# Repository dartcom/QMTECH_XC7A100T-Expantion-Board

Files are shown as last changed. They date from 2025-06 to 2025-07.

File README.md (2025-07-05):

# QMTECH_XC7A100T-Expantion-Board
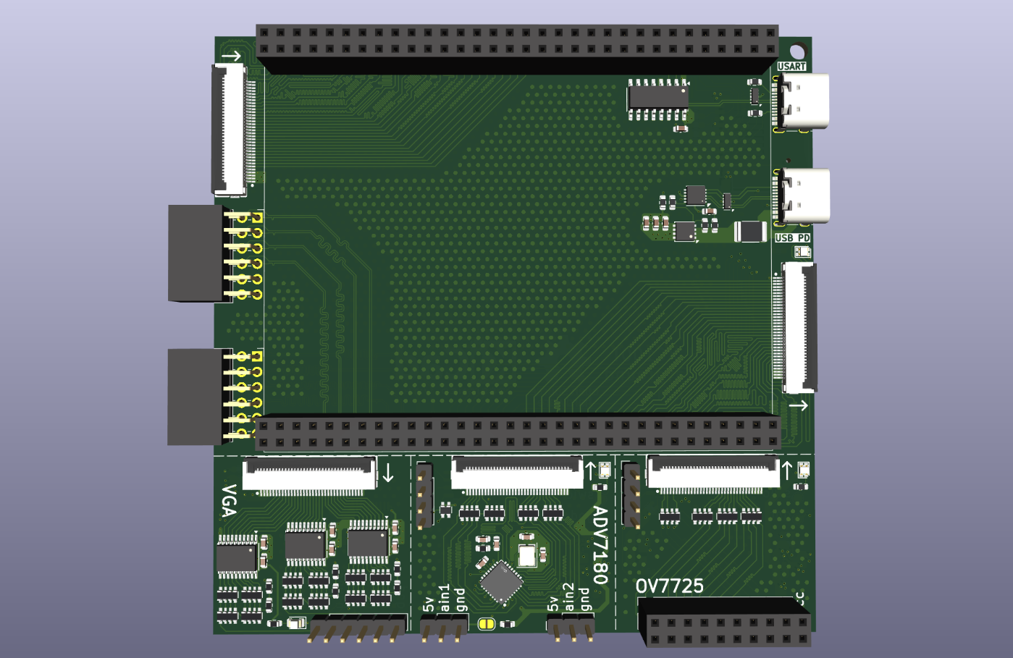
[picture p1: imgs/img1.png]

Expantion board for the QMTECH_XC7A***T series for video processing learning.

This board contains 4 separate designs to save on cost. The boards can be ordered as a single board and then be scored with a fresh exacto knife along the dotted lines ( ! BEWARE to not breathe the FR4 dust as it is VERY harmful ! ).

The main board contains:
- 2 PMOD connectors.
- 2 24bit parallel video connectors. The left is meant to be an input and the right one an output.
- 1 micro sd card slot.
- 1 uart to usb converter.
- 1 usb PD 5v-2A input with overvoltage & overcurrent protection.
- 8 leds.

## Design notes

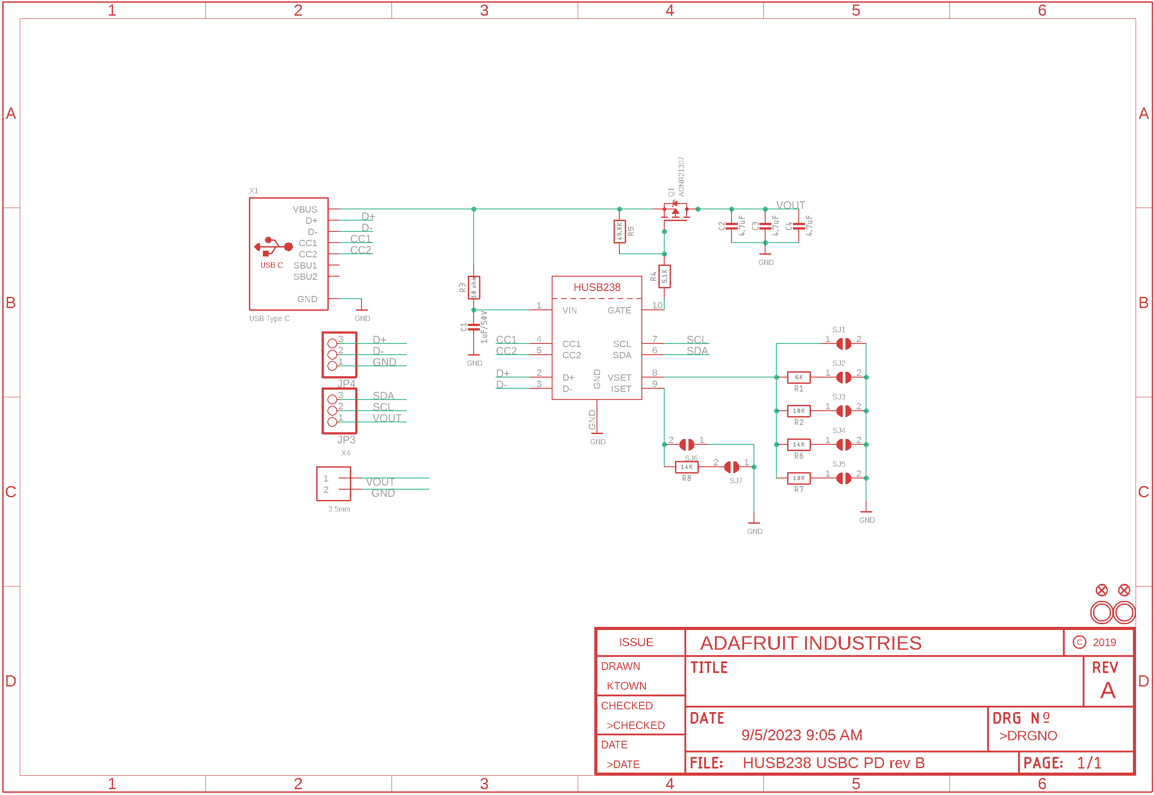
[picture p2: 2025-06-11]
datasheets/power/adafruit_products_schem.png

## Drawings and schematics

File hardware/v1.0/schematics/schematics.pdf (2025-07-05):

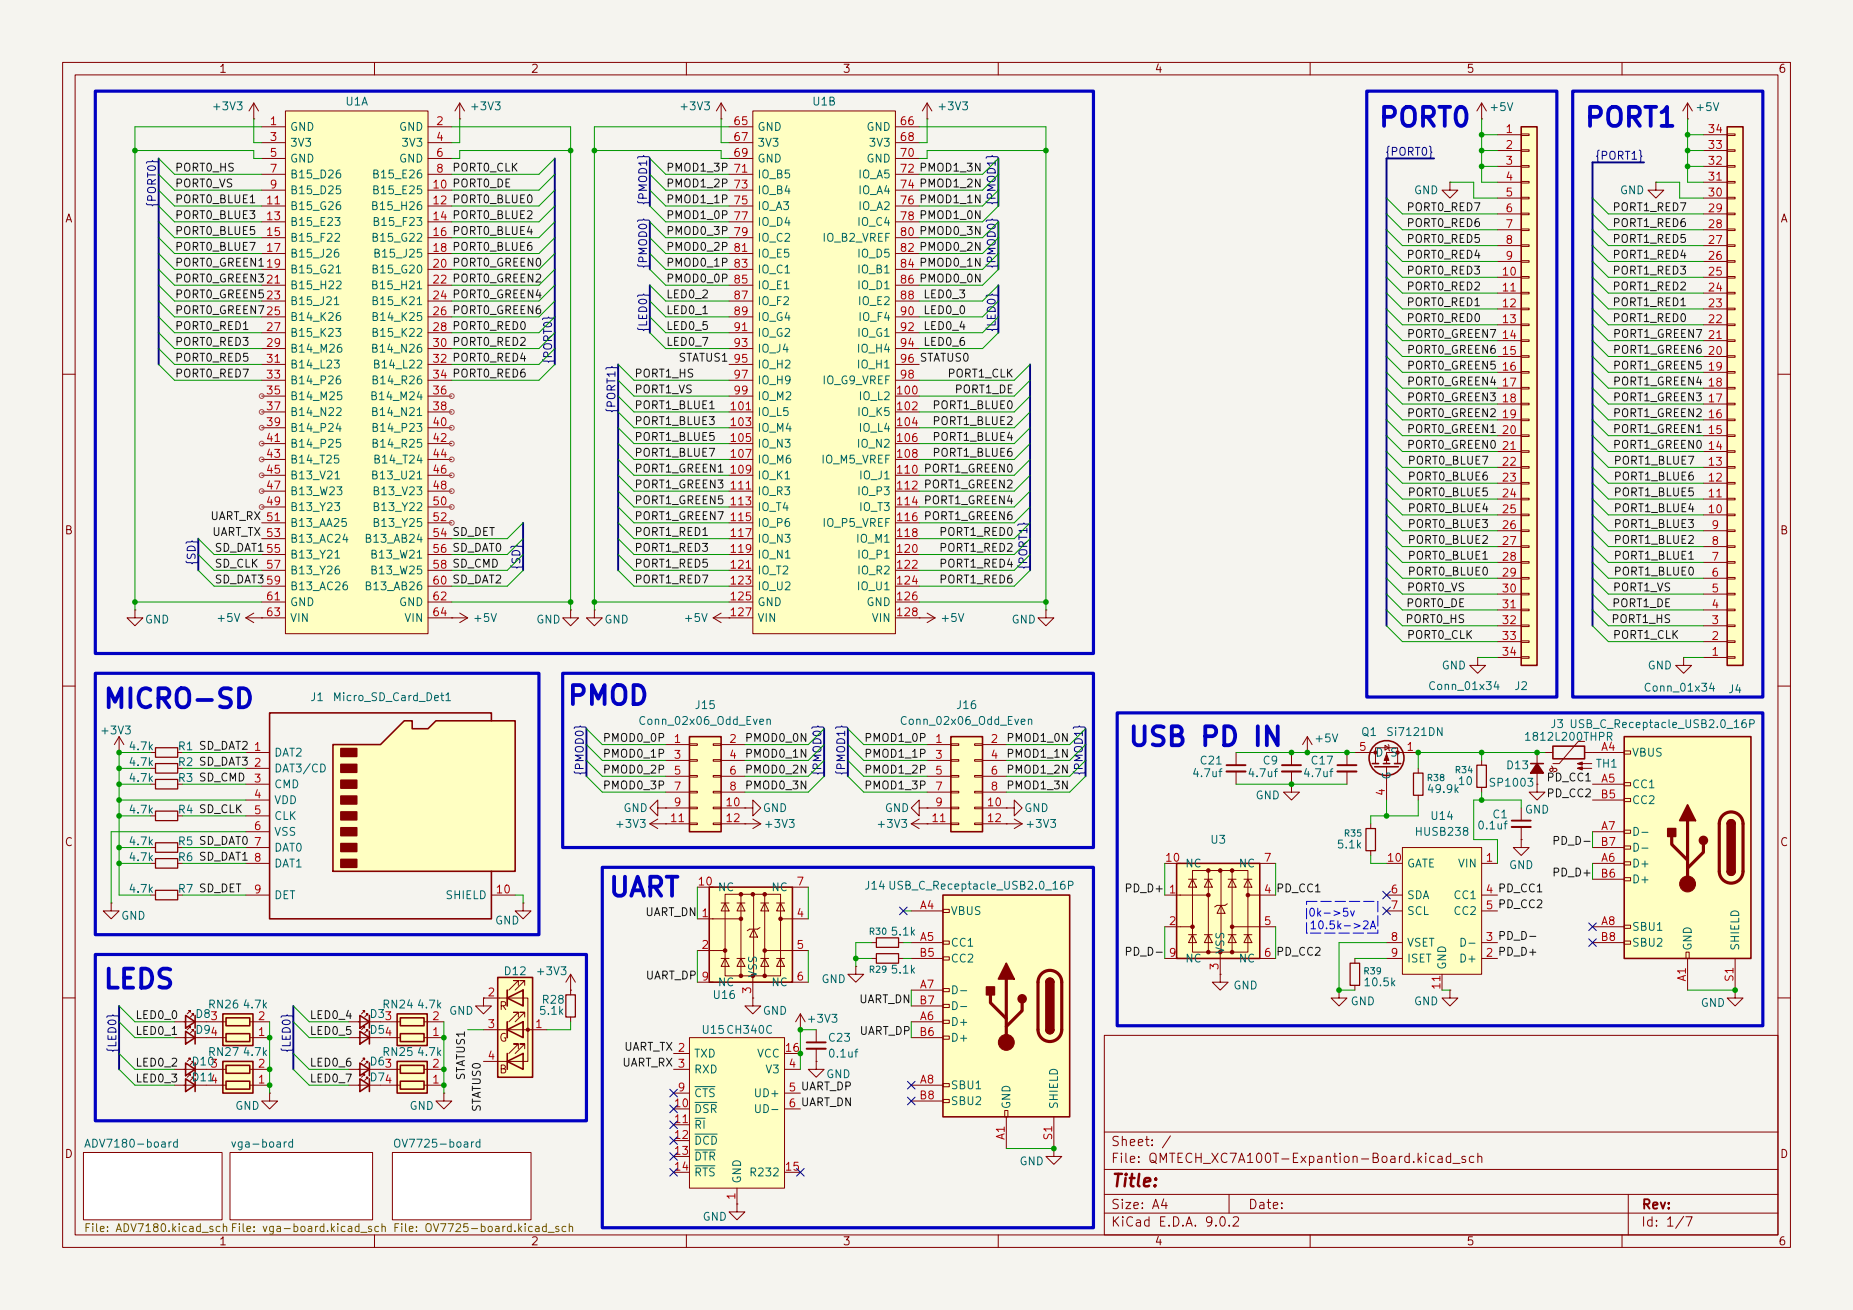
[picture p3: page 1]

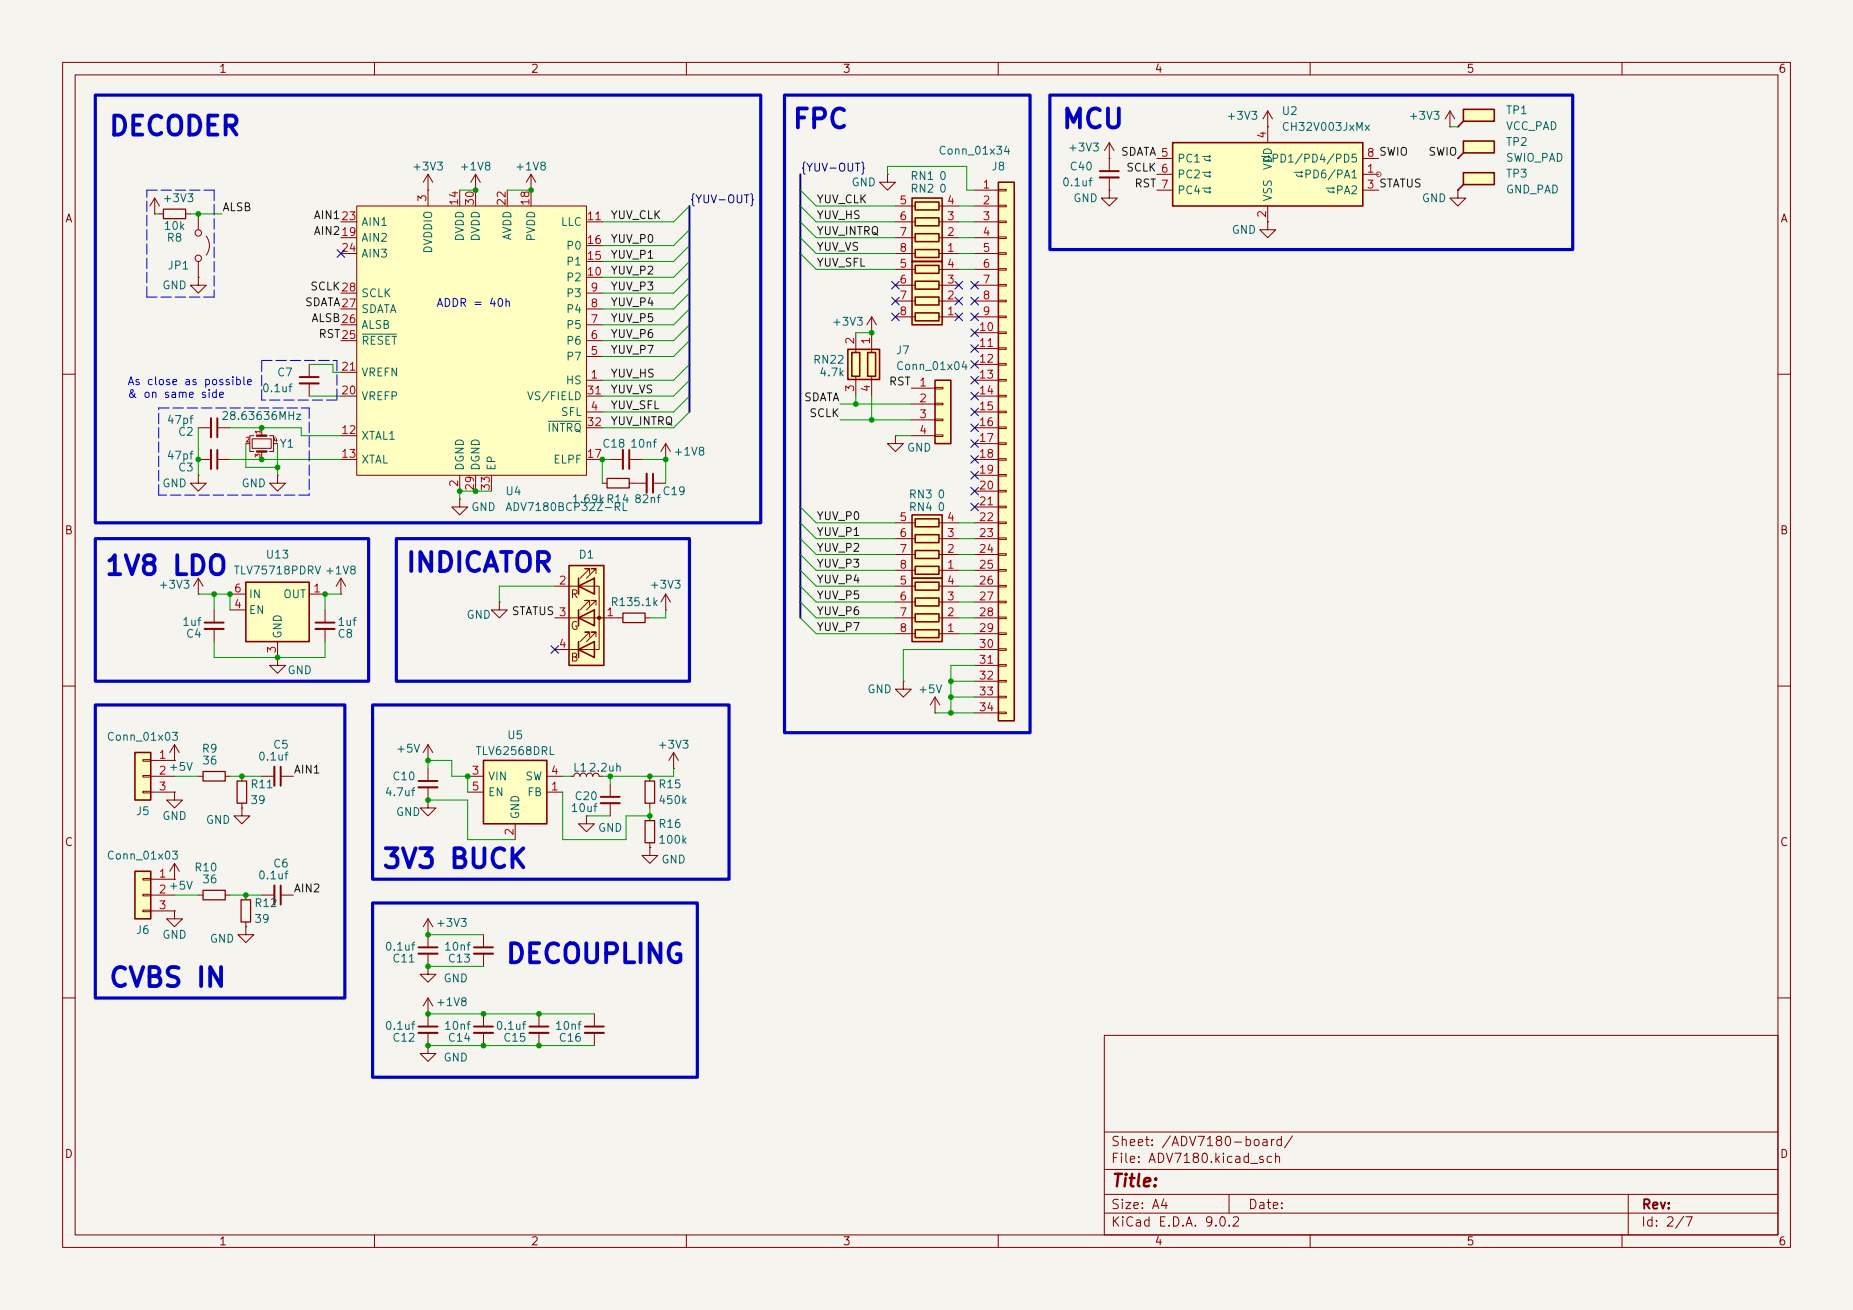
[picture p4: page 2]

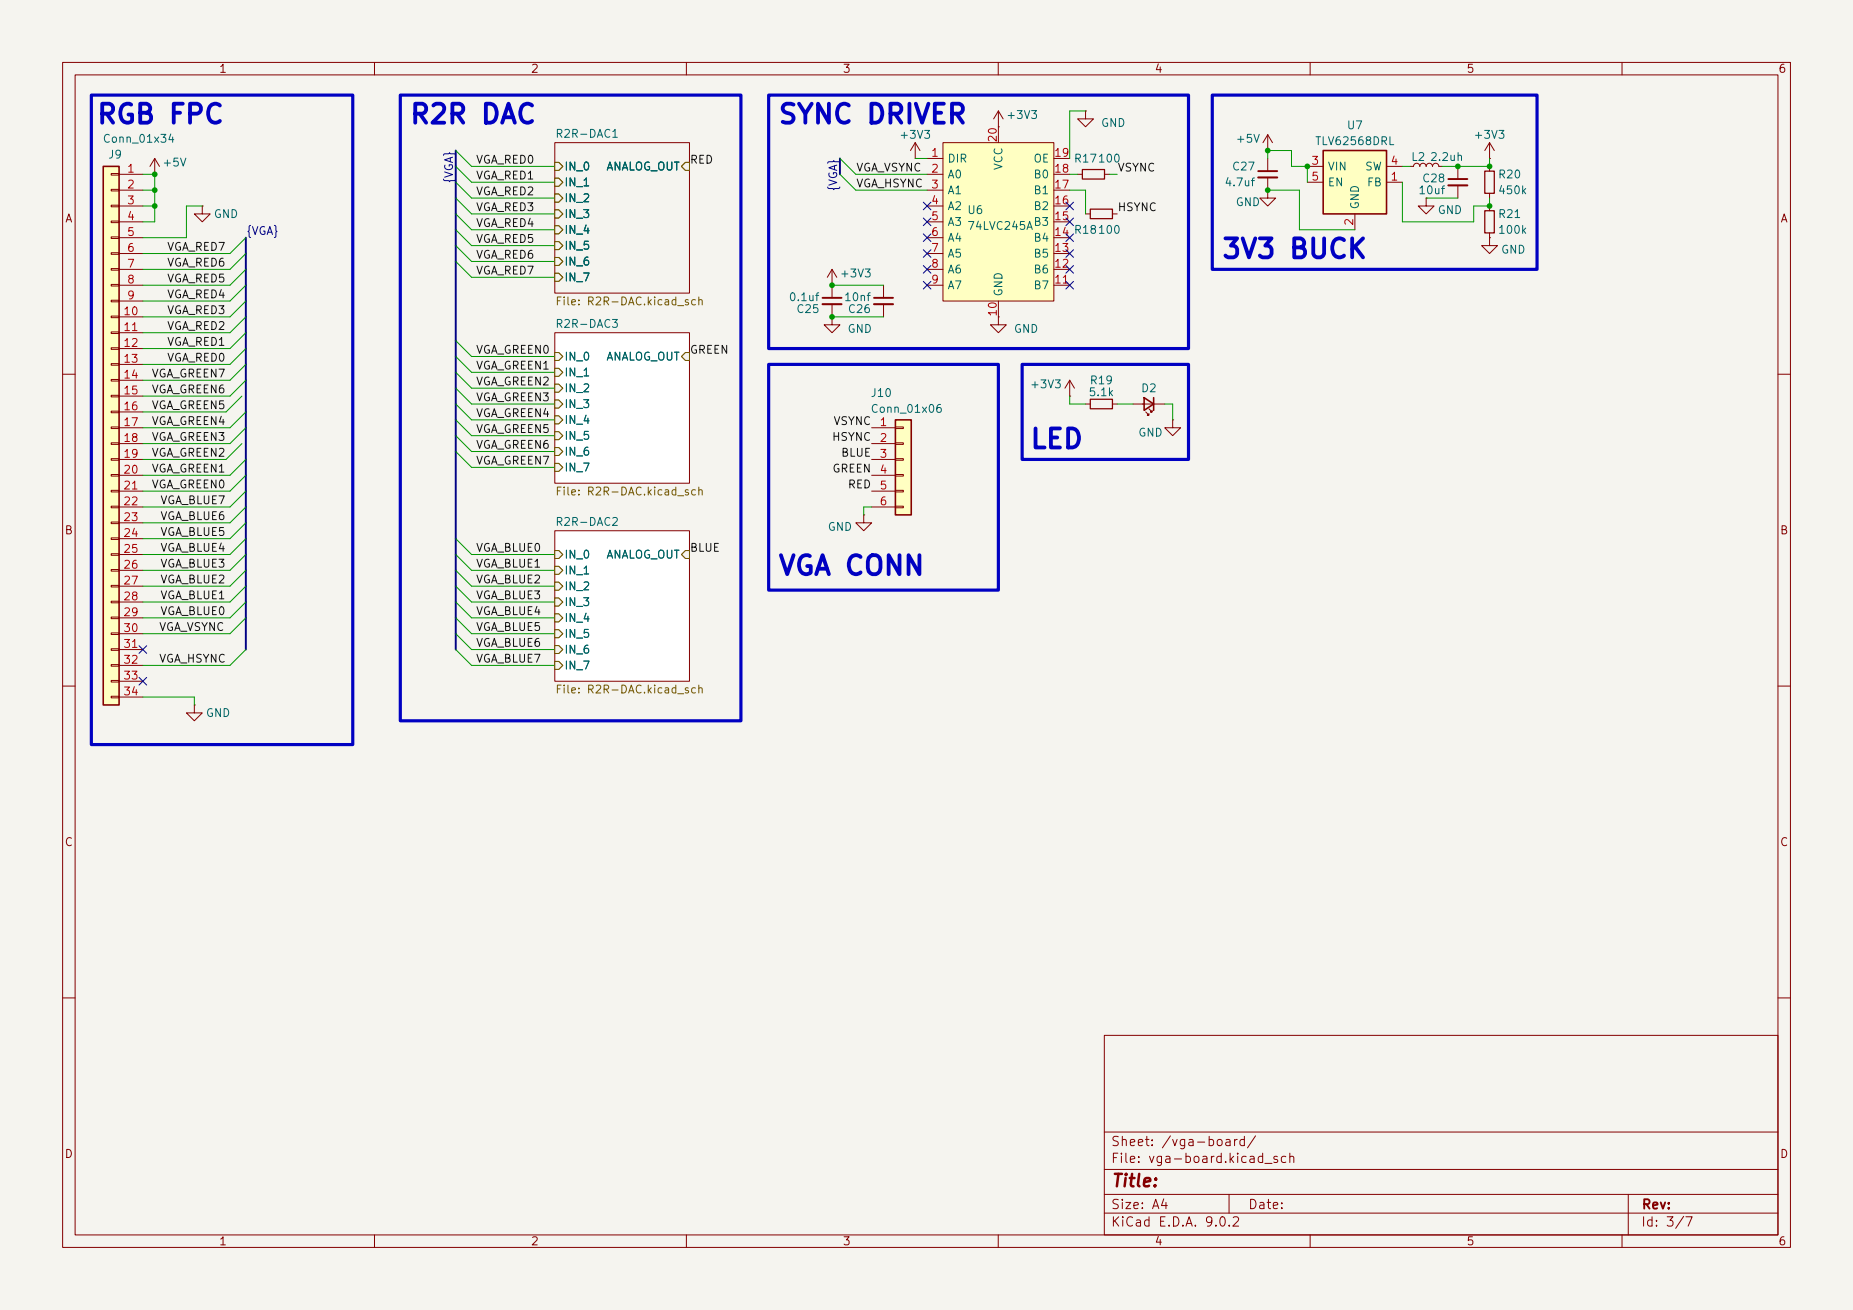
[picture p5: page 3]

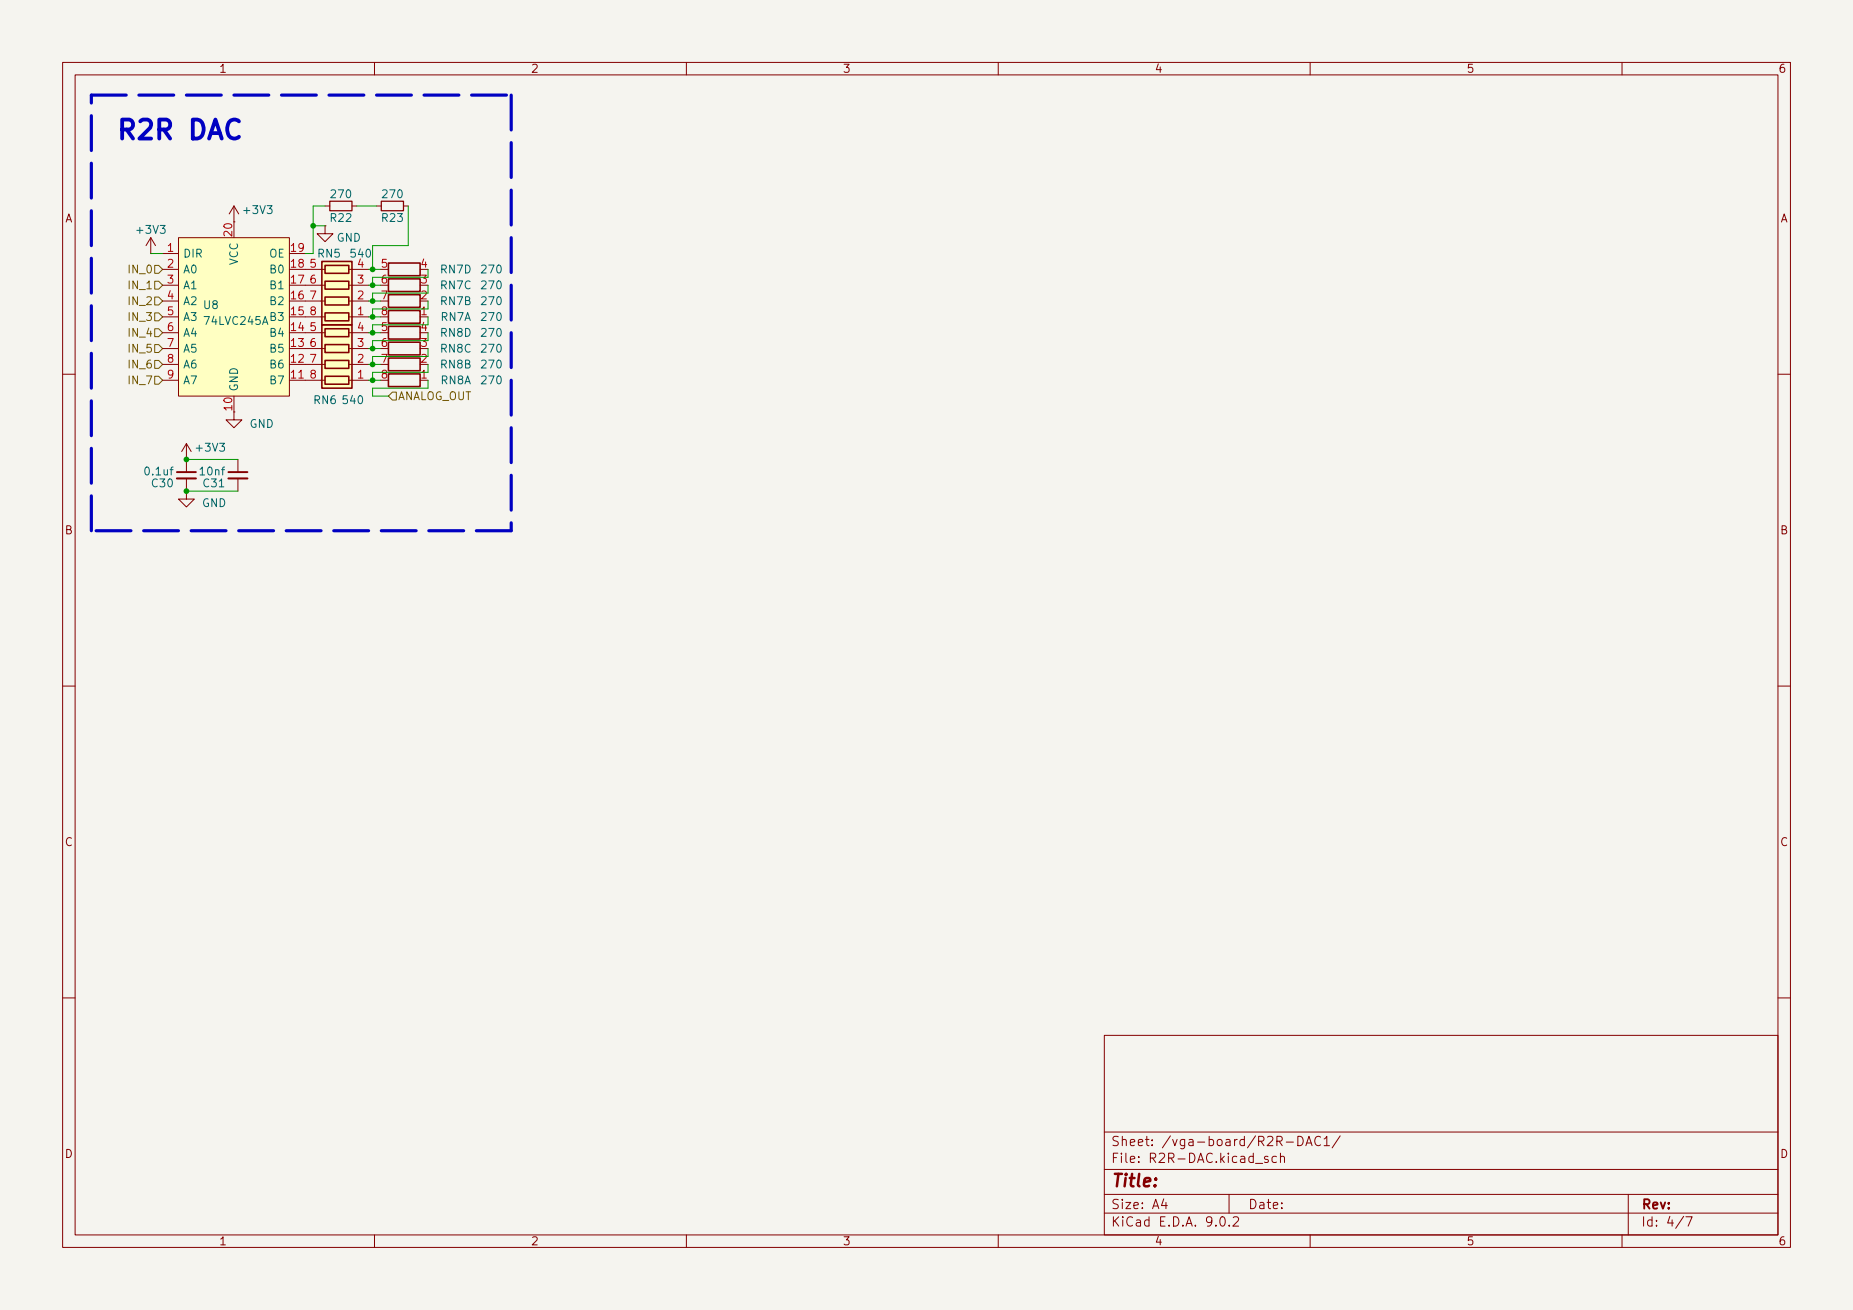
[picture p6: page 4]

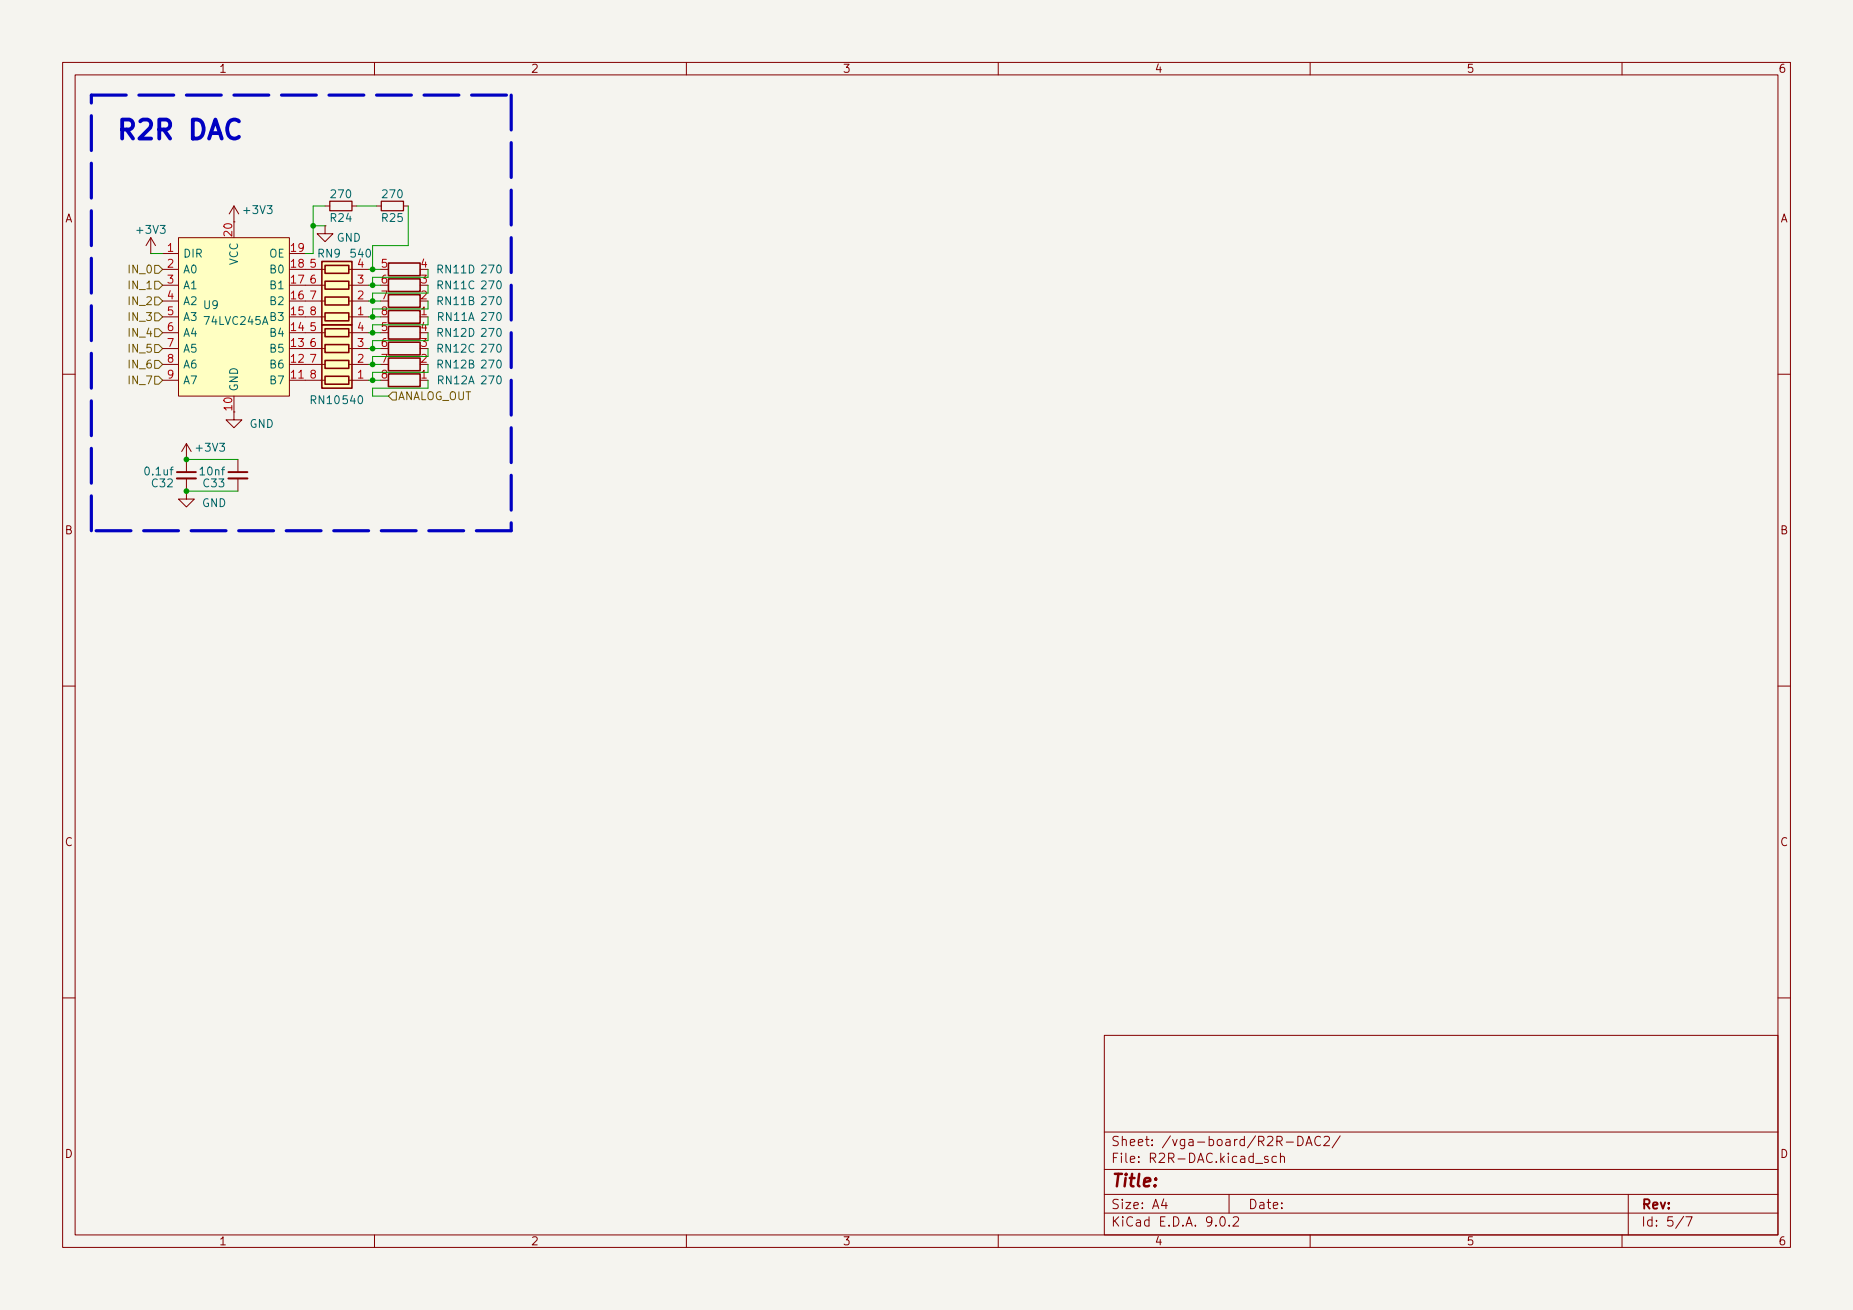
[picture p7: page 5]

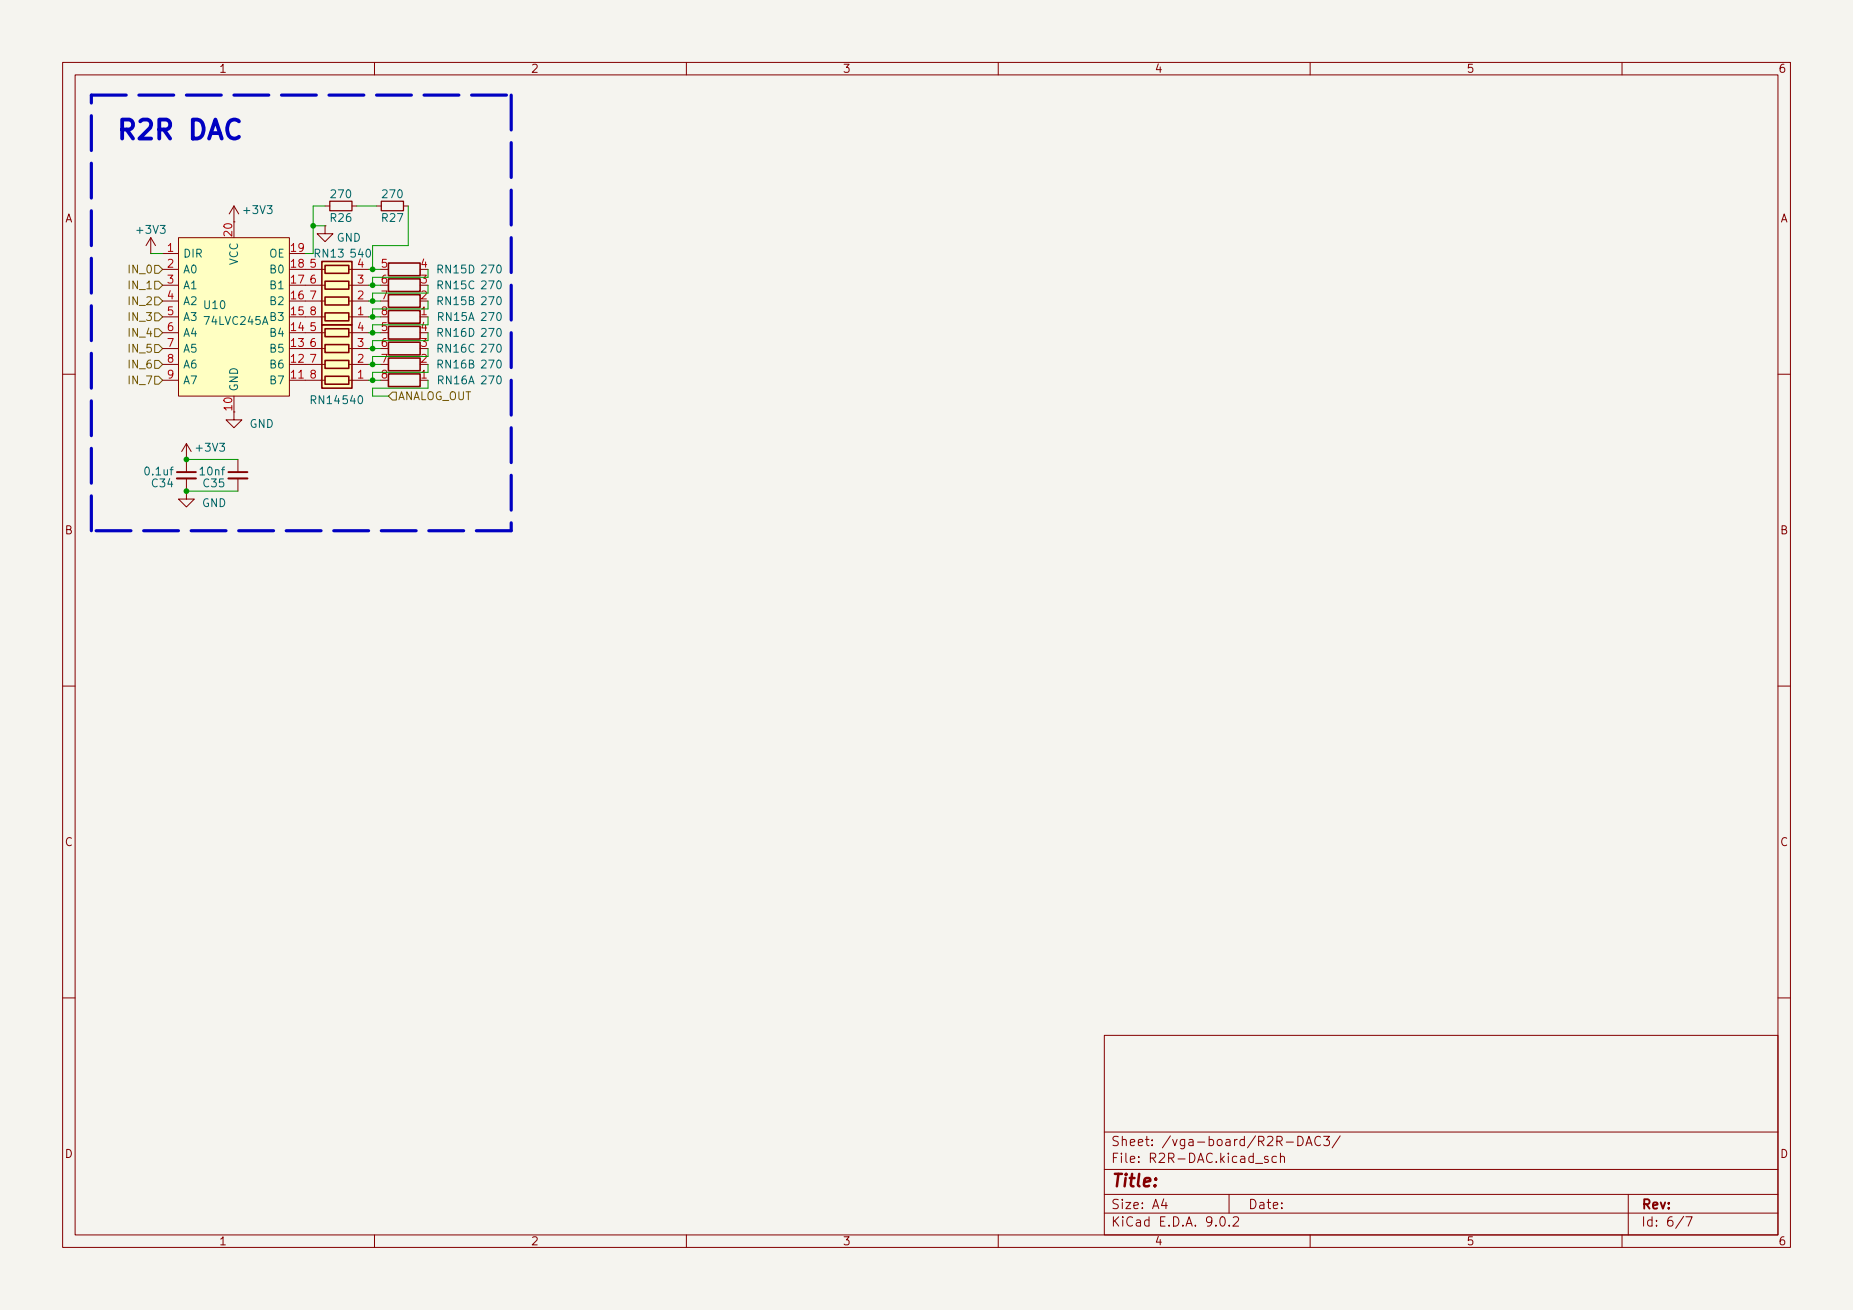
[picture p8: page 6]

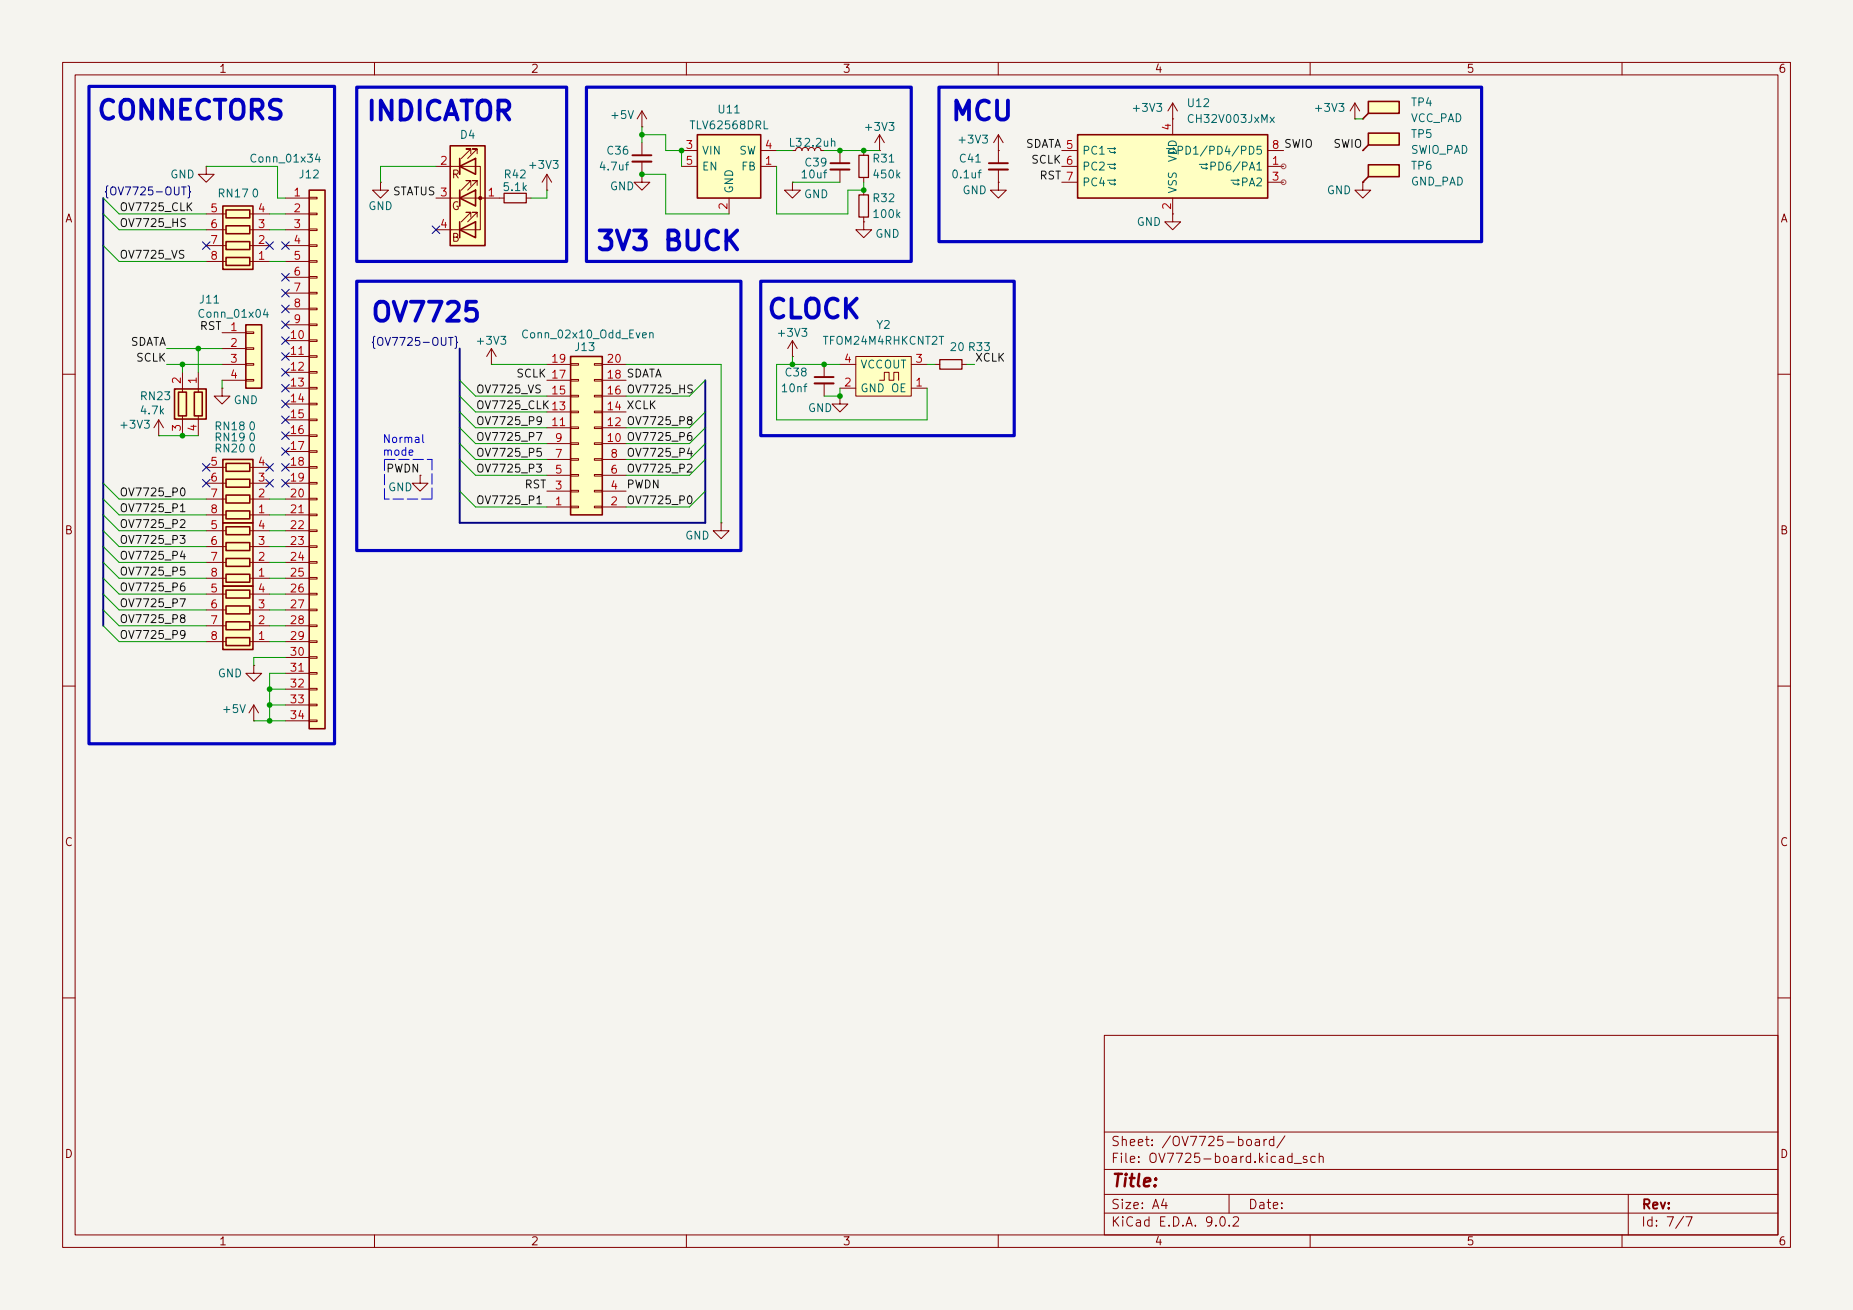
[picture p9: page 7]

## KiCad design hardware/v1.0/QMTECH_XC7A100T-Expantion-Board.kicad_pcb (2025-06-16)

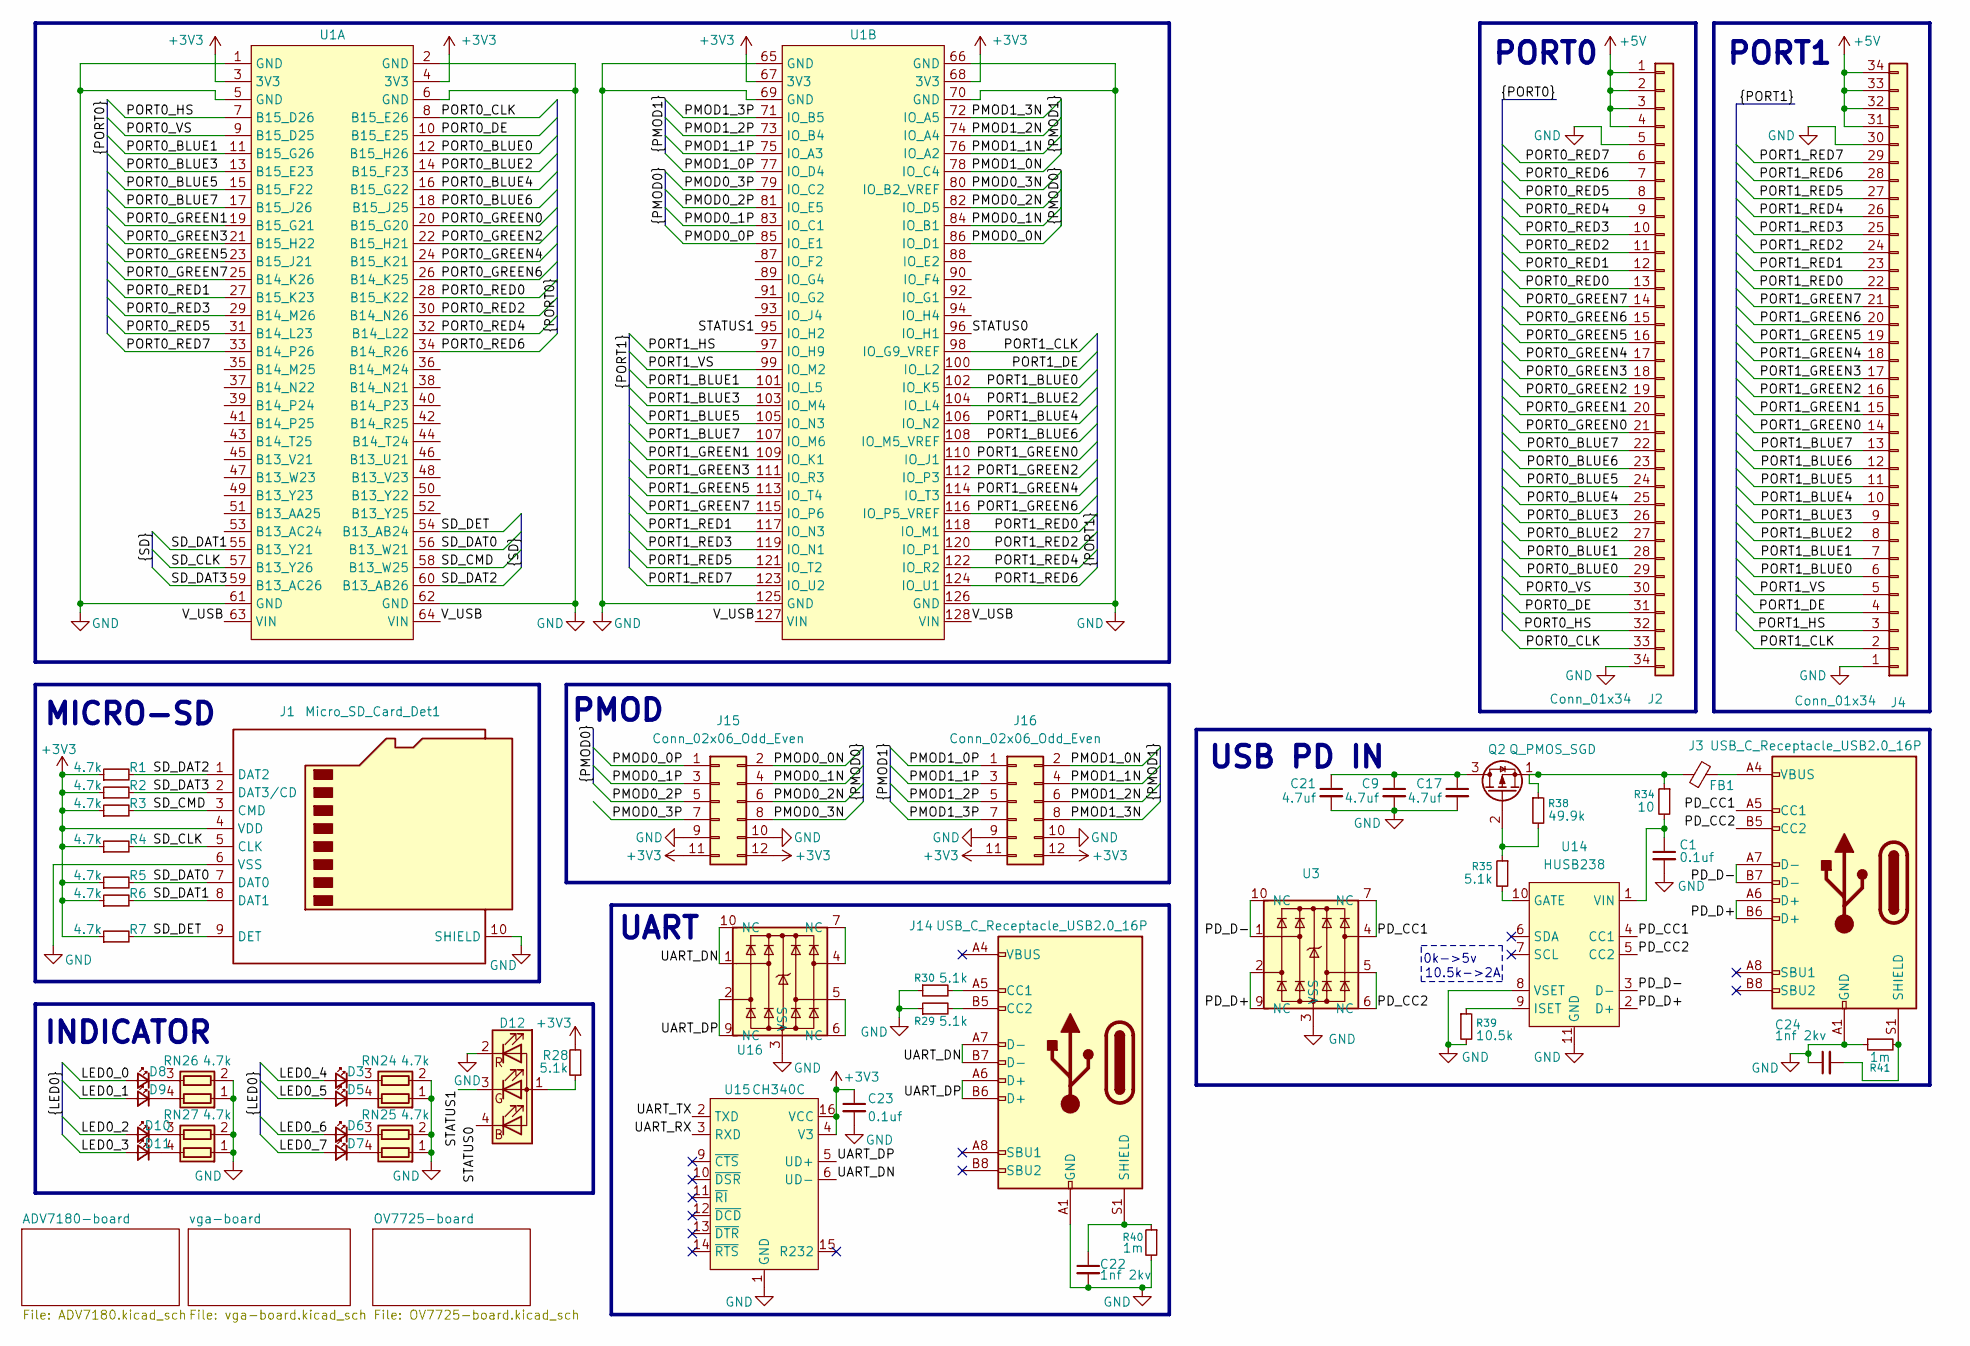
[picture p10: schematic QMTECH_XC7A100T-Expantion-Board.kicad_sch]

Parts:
C1, C23: 0.1uf
C9, C17, C21: 4.7uf
C22, C24: 1nf 2kv
D3, D5, D6, D7, D8, D9, D10, D11: LED_0805_2012Metric
D12: LED-SMD_4P-L1.6-W1.5-BR_TZ-P4-1615
FB1: (no value)
J1: Micro_SD_Card_Det1; TF-SMD_TF-PUSH
J2, J4: Conn_01x34; FPC-SMD_KH-FG0.5-H2.0-34PIN
J3, J14: USB_C_Receptacle_USB2.0_16P; USB_C_Receptacle_Palconn_UTC16-G
J15, J16: Conn_02x06_Odd_Even; PinSocket_2x06_P2.54mm_Horizontal
Q2: Q_PMOS_SGD; DFN-8-1EP_3x3mm_P0.5mm_EP1.7x2.4mm
R1, R2, R3, R4, R5, R6, R7: 4.7k; R_0603_1608Metric_Pad0.98x0.95mm_HandSolder
R28: 5.1k; R_0603_1608Metric_Pad0.98x0.95mm_HandSolder
R29, R30: 5.1k; R_0603_1608Metric
R34: 10
R35: 5.1k
R38: 49.9k
R39: 10.5k
R40, R41: 1m
RN24, RN25, RN26, RN27: 4.7k; R_Array_Convex_2x0603
U1: QMTECH_XC7A___T
U3, U16: Diodes_UDFN-10_1.0x2.5mm_P0.5mm
U14: HUSB238; DFN-10-1EP_3x3mm_P0.5mm_EP1.65x2.38mm_ThermalVias
U15: CH340C; SOIC-16_3.9x9.9mm_P1.27mm

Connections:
+3V3: C23.1, J1.4 (VDD), J15.11, J15.12, J16.11, J16.12, R1.1, R2.1, R3.1, R4.1, R5.1, R6.1, R7.1, R28.2, U1.3 (3V3), U1.4 (3V3), U1.67 (3V3), U1.68 (3V3), U15.4 (V3), U15.16 (VCC); also elsewhere on the board
+5V: J2.1, J2.2, J2.3, J2.4, J4.31, J4.32, J4.33, J4.34; also elsewhere on the board
/LED0_0: D8.2 (A)
/LED0_1: D9.2 (A)
/LED0_2: D10.2 (A)
/LED0_3: D11.2 (A)
/LED0_4: D3.2 (A)
/LED0_5: D5.2 (A)
/LED0_6: D6.2 (A)
/LED0_7: D7.2 (A)
/PD_CC1: J3.A5 (CC1), U3.4, U3.7 (NC), U14.4 (CC1)
/PD_CC2: J3.B5 (CC2), U3.5, U3.6 (NC), U14.5 (CC2)
/PD_D+: J3.A6 (D+), J3.B6 (D+), U3.2, U3.9 (NC), U14.2 (D+)
/PD_D-: J3.A7 (D-), J3.B7 (D-), U3.1, U3.10 (NC), U14.3 (D-)
/PMOD0_0N: J15.2, U1.86 (IO_D1)
/PMOD0_0P: J15.1, U1.85 (IO_E1)
/PMOD0_1N: J15.4, U1.84 (IO_B1)
/PMOD0_1P: J15.3, U1.83 (IO_C1)
/PMOD0_2N: J15.6, U1.82 (IO_D5)
/PMOD0_2P: J15.5, U1.81 (IO_E5)
/PMOD0_3N: J15.8, U1.80 (IO_B2_VREF)
/PMOD0_3P: J15.7, U1.79 (IO_C2)
/PMOD1_0N: J16.2, U1.78 (IO_C4)
/PMOD1_0P: J16.1, U1.77 (IO_D4)
/PMOD1_1N: J16.4, U1.76 (IO_A2)
/PMOD1_1P: J16.3, U1.75 (IO_A3)
/PMOD1_2N: J16.6, U1.74 (IO_A4)
/PMOD1_2P: J16.5, U1.73 (IO_B4)
/PMOD1_3N: J16.8, U1.72 (IO_A5)
/PMOD1_3P: J16.7, U1.71 (IO_B5)
/PORT0_BLUE0: J2.29, U1.12 (B15_H26)
/PORT0_BLUE1: J2.28, U1.11 (B15_G26)
/PORT0_BLUE2: J2.27, U1.14 (B15_F23)
/PORT0_BLUE3: J2.26, U1.13 (B15_E23)
/PORT0_BLUE4: J2.25, U1.16 (B15_G22)
/PORT0_BLUE5: J2.24, U1.15 (B15_F22)
/PORT0_BLUE6: J2.23, U1.18 (B15_J25)
/PORT0_BLUE7: J2.22, U1.17 (B15_J26)
/PORT0_CLK: J2.33, U1.8 (B15_E26)
/PORT0_DE: J2.31, U1.10 (B15_E25)
/PORT0_GREEN0: J2.21, U1.20 (B15_G20)
/PORT0_GREEN1: J2.20, U1.19 (B15_G21)
/PORT0_GREEN2: J2.19, U1.22 (B15_H21)
/PORT0_GREEN3: J2.18, U1.21 (B15_H22)
/PORT0_GREEN4: J2.17, U1.24 (B15_K21)
/PORT0_GREEN5: J2.16, U1.23 (B15_J21)
/PORT0_GREEN6: J2.15, U1.26 (B14_K25)
/PORT0_GREEN7: J2.14, U1.25 (B14_K26)
/PORT0_HS: J2.32, U1.7 (B15_D26)
/PORT0_RED0: J2.13, U1.28 (B15_K22)
/PORT0_RED1: J2.12, U1.27 (B15_K23)
/PORT0_RED2: J2.11, U1.30 (B14_N26)
/PORT0_RED3: J2.10, U1.29 (B14_M26)
/PORT0_RED4: J2.9, U1.32 (B14_L22)
/PORT0_RED5: J2.8, U1.31 (B14_L23)
/PORT0_RED6: J2.7, U1.34 (B14_R26)
/PORT0_RED7: J2.6, U1.33 (B14_P26)
/PORT0_VS: J2.30, U1.9 (B15_D25)
/PORT1_BLUE0: J4.6, U1.102 (IO_K5)
/PORT1_BLUE1: J4.7, U1.101 (IO_L5)
/PORT1_BLUE2: J4.8, U1.104 (IO_L4)
/PORT1_BLUE3: J4.9, U1.103 (IO_M4)
/PORT1_BLUE4: J4.10, U1.106 (IO_N2)
/PORT1_BLUE5: J4.11, U1.105 (IO_N3)
/PORT1_BLUE6: J4.12, U1.108 (IO_M5_VREF)
/PORT1_BLUE7: J4.13, U1.107 (IO_M6)
/PORT1_CLK: J4.2, U1.98 (IO_G9_VREF)
/PORT1_DE: J4.4, U1.100 (IO_L2)
/PORT1_GREEN0: J4.14, U1.110 (IO_J1)
/PORT1_GREEN1: J4.15, U1.109 (IO_K1)
/PORT1_GREEN2: J4.16, U1.112 (IO_P3)
/PORT1_GREEN3: J4.17, U1.111 (IO_R3)
/PORT1_GREEN4: J4.18, U1.114 (IO_T3)
/PORT1_GREEN5: J4.19, U1.113 (IO_T4)
/PORT1_GREEN6: J4.20, U1.116 (IO_P5_VREF)
/PORT1_GREEN7: J4.21, U1.115 (IO_P6)
/PORT1_HS: J4.3, U1.97 (IO_H9)
/PORT1_RED0: J4.22, U1.118 (IO_M1)
/PORT1_RED1: J4.23, U1.117 (IO_N3)
/PORT1_RED2: J4.24, U1.120 (IO_P1)
/PORT1_RED3: J4.25, U1.119 (IO_N1)
/PORT1_RED4: J4.26, U1.122 (IO_R2)
/PORT1_RED5: J4.27, U1.121 (IO_T2)
/PORT1_RED6: J4.28, U1.124 (IO_U1)
/PORT1_RED7: J4.29, U1.123 (IO_U2)
/PORT1_VS: J4.5, U1.99 (IO_M2)
/SD_CLK: J1.5 (CLK), R4.2, U1.57 (B13_Y26)
/SD_CMD: J1.3 (CMD), R3.2, U1.58 (B13_W25)
/SD_DAT0: J1.7 (DAT0), R5.2, U1.56 (B13_W21)
/SD_DAT1: J1.8 (DAT1), R6.2, U1.55 (B13_Y21)
/SD_DAT2: J1.1 (DAT2), R1.2, U1.60 (B13_AB26)
/SD_DAT3: J1.2 (DAT3/CD), R2.2, U1.59 (B13_AC26)
/SD_DET: J1.9 (DET), R7.2, U1.54 (B13_AB24)
/STATUS0: D12.4 (BK), U1.96 (IO_H1)
/STATUS1: D12.3 (GK), U1.95 (IO_H2)
/UART_DN: J14.A7 (D-), J14.B7 (D-), U15.6 (UD-), U16.1, U16.10 (NC)
/UART_DP: J14.A6 (D+), J14.B6 (D+), U15.5 (UD+), U16.2, U16.9 (NC)
/UART_RX: U15.3 (RXD)
/UART_TX: U15.2 (TXD)
/V_USB: U1.63 (VIN), U1.64 (VIN), U1.127 (VIN), U1.128 (VIN)
GND: C1.2, C9.2, C17.2, C21.2, C22.2, C23.2, C24.1, D12.2 (RK), J1.6 (VSS), J1.10 (SHIELD), J2.5, J2.34, J3.A1 (GND), J3.A12 (GND), J3.B1 (GND), J3.B12 (GND), J4.1, J4.30, J14.A1 (GND), J14.A12 (GND), J14.B1 (GND), J14.B12 (GND), J15.9, J15.10, J16.9, J16.10, R29.1, R30.1, R39.2, R40.2, R41.1, RN24.1 (R1.1), RN24.2 (R2.1), RN25.1 (R1.1), RN25.2 (R2.1), RN26.1 (R1.1), RN26.2 (R2.1), RN27.1 (R1.1), RN27.2 (R2.1), U1.1 (GND), U1.2 (GND), U1.5 (GND), U1.6 (GND), U1.61 (GND), U1.62 (GND), U1.65 (GND), U1.66 (GND), U1.69 (GND), U1.70 (GND), U1.125 (GND), U1.126 (GND), U3.3 (VSS), U3.8 (VSS), U14.8 (VSET), U14.11 (GND), U15.1 (GND), U16.3 (VSS), U16.8 (VSS); also elsewhere on the board
unnamed: D3.1 (K), RN24.3 (R2.2)
unnamed: D5.1 (K), RN24.4 (R1.2)
unnamed: D6.1 (K), RN25.3 (R2.2)
unnamed: D7.1 (K), RN25.4 (R1.2)
unnamed: D8.1 (K), RN26.3 (R2.2)
unnamed: D9.1 (K), RN26.4 (R1.2)
unnamed: D10.1 (K), RN27.3 (R2.2)
unnamed: D11.1 (K), RN27.4 (R1.2)
unnamed: D12.1 (A), R28.1
unnamed: FB1.2, J3.A4 (VBUS), J3.A9 (VBUS), J3.B4 (VBUS), J3.B9 (VBUS)
unnamed: C24.2, J3.S1 (SHIELD), R41.2
unnamed: J14.A5 (CC1), R30.2
unnamed: J14.B5 (CC2), R29.2
unnamed: C22.1, J14.S1 (SHIELD), R40.1
unnamed: C9.1, C17.1, C21.1, Q2.3 (D)
unnamed: Q2.2 (G), R35.1, R38.2
unnamed: FB1.1, Q2.1 (S), R34.1, R38.1
unnamed: R35.2, U14.10 (GATE)
unnamed: R39.1, U14.9 (ISET)
unnamed: C1.1, R34.2, U14.1 (VIN)
unnamed: U16.5, U16.6 (NC)
unnamed: U16.4, U16.7 (NC)

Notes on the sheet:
PORT0
PORT1
PMOD
MICRO-SD
10.5k->2A
UART
USB PD IN
0k->5v
INDICATOR

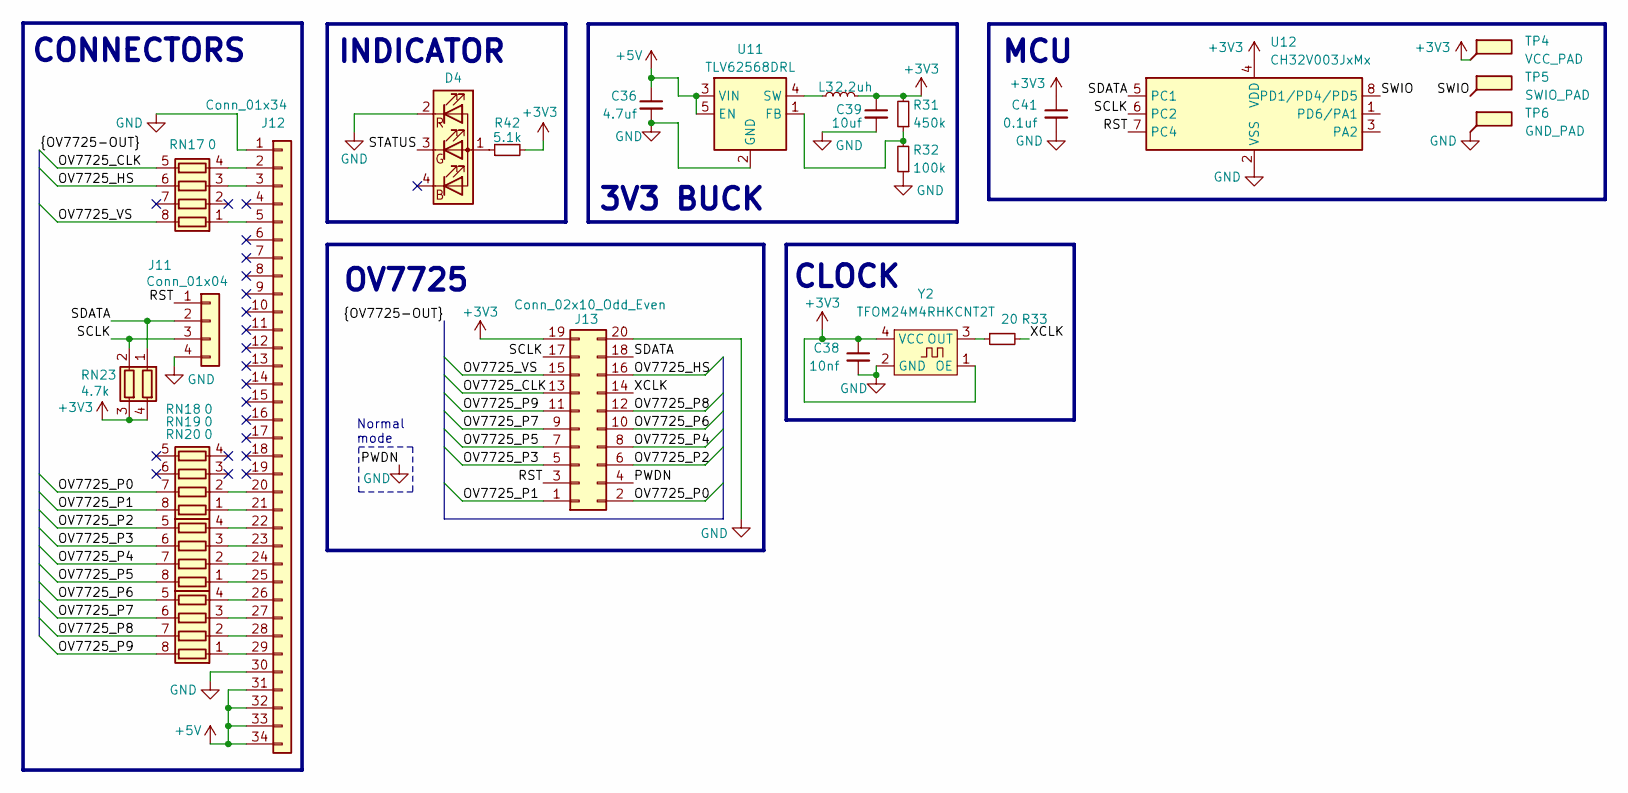
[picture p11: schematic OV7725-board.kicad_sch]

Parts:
C36: 4.7uf; C_0603_1608Metric
C38: 10nf; C_0603_1608Metric
C39: 10uf; C_0603_1608Metric
C41: 0.1uf; C_0603_1608Metric
D4: LED-SMD_4P-L1.6-W1.5-BR_TZ-P4-1615
J11: Conn_01x04; PinHeader_1x04_P2.54mm_Vertical
J12: Conn_01x34; FPC-SMD_KH-FG0.5-H2.0-34PIN
J13: Conn_02x10_Odd_Even; PinSocket_2x10_P2.54mm_Vertical
L3: 2.2uh; L_0603_1608Metric
R31: 450k; R_0603_1608Metric
R32: 100k; R_0603_1608Metric
R33: 20; R_0603_1608Metric
R42: 5.1k; R_0603_1608Metric
RN17, RN18, RN19, RN20: 0; R_Array_Convex_4x0603
RN23: 4.7k; R_Array_Convex_2x0603
TP4: VCC_PAD; TestPoint_Pad_D1.5mm
TP5: SWIO_PAD; TestPoint_Pad_D1.5mm
TP6: GND_PAD; TestPoint_Pad_D1.5mm
U11: TLV62568DRL; SOT-563
U12: CH32V003JxMx; SOP-8_3.9x4.9mm_P1.27mm
Y2: TFOM24M4RHKCNT2T

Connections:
+3V3: C38.1, C39.1, C41.1, J13.19, L3.2, R31.2, R42.2, RN23.3 (R2.2), RN23.4 (R1.2), TP4.1, U12.4 (VDD), Y2.1 (OE), Y2.4 (VCC); also elsewhere on the board
+5V: C36.1, J12.31, J12.32, J12.33, J12.34, U11.3 (VIN), U11.5 (EN); also elsewhere on the board
/OV7725-board/OV7725_CLK: J13.13, RN17.5 (R4.2)
/OV7725-board/OV7725_HS: J13.16, RN17.6 (R3.2)
/OV7725-board/OV7725_P0: J13.2, RN18.7 (R2.2)
/OV7725-board/OV7725_P1: J13.1, RN18.8 (R1.2)
/OV7725-board/OV7725_P2: J13.6, RN19.5 (R4.2)
/OV7725-board/OV7725_P3: J13.5, RN19.6 (R3.2)
/OV7725-board/OV7725_P4: J13.8, RN19.7 (R2.2)
/OV7725-board/OV7725_P5: J13.7, RN19.8 (R1.2)
/OV7725-board/OV7725_P6: J13.10, RN20.5 (R4.2)
/OV7725-board/OV7725_P7: J13.9, RN20.6 (R3.2)
/OV7725-board/OV7725_P8: J13.12, RN20.7 (R2.2)
/OV7725-board/OV7725_P9: J13.11, RN20.8 (R1.2)
/OV7725-board/OV7725_VS: J13.15, RN17.8 (R1.2)
/OV7725-board/RST: J11.1, J13.3, U12.7 (PC4)
/OV7725-board/SCLK: J11.3, J13.17, RN23.2 (R2.1), U12.6 (PC2)
/OV7725-board/SDATA: J11.2, J13.18, RN23.1 (R1.1), U12.5 (PC1)
/OV7725-board/STATUS: D4.3 (GK)
/OV7725-board/SWIO: TP5.1, U12.8 (PD1/PD4/PD5)
/OV7725-board/XCLK: J13.14, R33.2
GND: C36.2, C38.2, C39.2, C41.2, D4.2 (RK), J11.4, J12.1, J12.30, J13.4, J13.20, R32.1, TP6.1, U11.2 (GND), U12.2 (VSS), Y2.2 (GND); also elsewhere on the board
unnamed: D4.1 (A), R42.1
unnamed: J12.2, RN17.4 (R4.1)
unnamed: J12.3, RN17.3 (R3.1)
unnamed: J12.5, RN17.1 (R1.1)
unnamed: J12.20, RN18.2 (R2.1)
unnamed: J12.21, RN18.1 (R1.1)
unnamed: J12.22, RN19.4 (R4.1)
unnamed: J12.23, RN19.3 (R3.1)
unnamed: J12.24, RN19.2 (R2.1)
unnamed: J12.25, RN19.1 (R1.1)
unnamed: J12.26, RN20.4 (R4.1)
unnamed: J12.27, RN20.3 (R3.1)
unnamed: J12.28, RN20.2 (R2.1)
unnamed: J12.29, RN20.1 (R1.1)
unnamed: R31.1, R32.2, U11.1 (FB)
unnamed: L3.1, U11.4 (SW)
unnamed: R33.1, Y2.3 (OUT)

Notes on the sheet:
CLOCK
MCU
OV7725
INDICATOR
Normal mode
CONNECTORS
3V3 BUCK

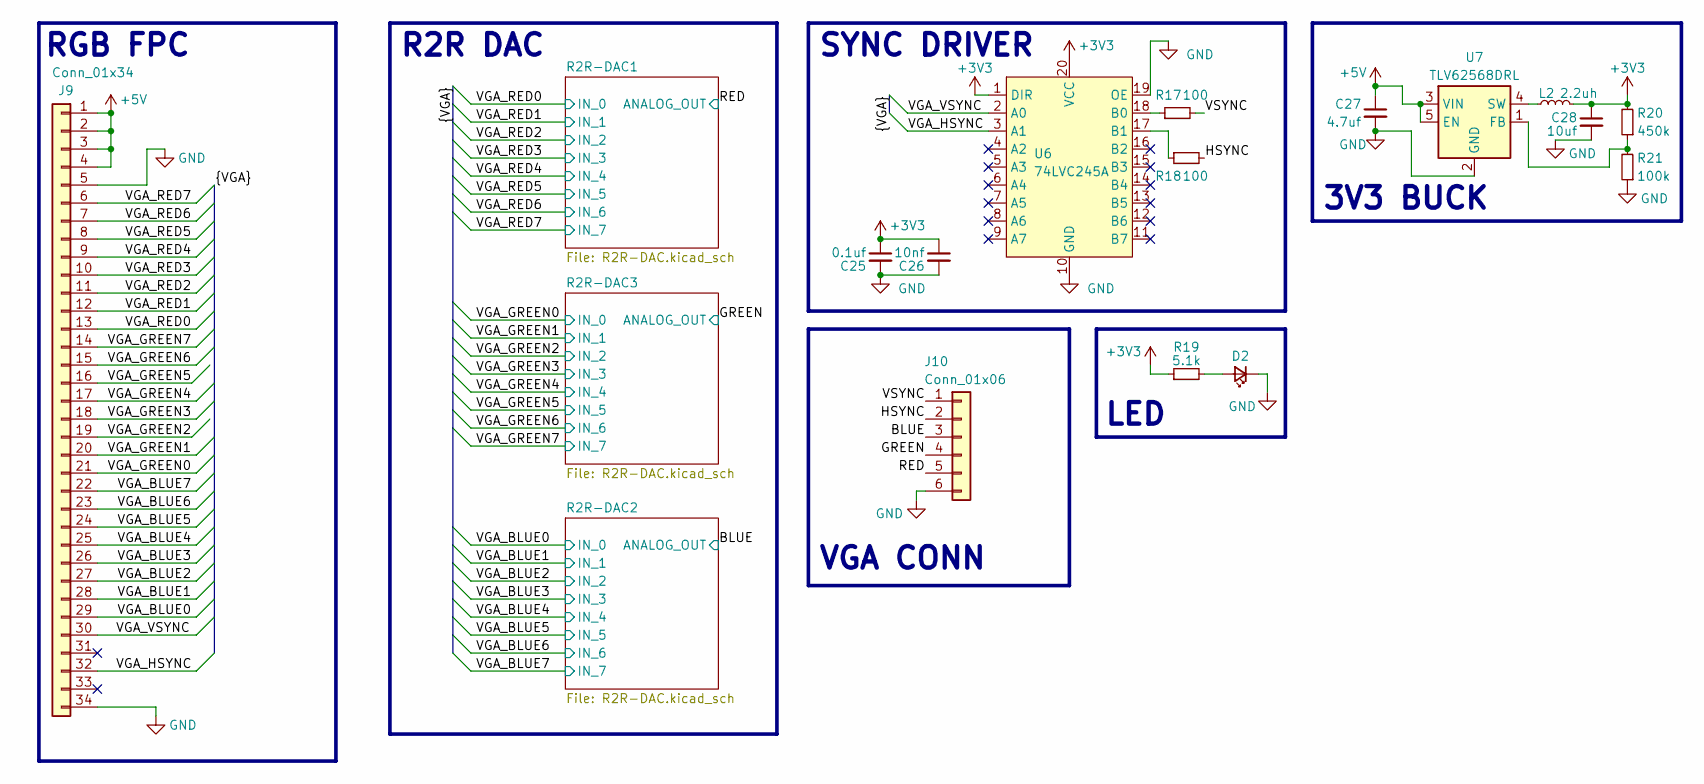
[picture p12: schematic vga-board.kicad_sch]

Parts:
C25: 0.1uf; C_0603_1608Metric
C26: 10nf; C_0603_1608Metric
C27: 4.7uf; C_0603_1608Metric
C28: 10uf; C_0603_1608Metric
D2: LED_0402_1005Metric_Pad0.77x0.64mm_HandSolder
J9: Conn_01x34; FPC-SMD_KH-FG0.5-H2.0-34PIN
J10: Conn_01x06; PinHeader_1x06_P2.54mm_Vertical
L2: 2.2uh; L_0603_1608Metric
R17, R18: 100; R_0603_1608Metric
R19: 5.1k; R_0603_1608Metric
R20: 450k; R_0603_1608Metric
R21: 100k; R_0603_1608Metric
U6: 74LVC245A; TSSOP-20_4.4x6.5mm_P0.65mm
U7: TLV62568DRL; SOT-563

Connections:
+3V3: C25.1, C26.1, C28.1, L2.2, R19.1, R20.2, U6.1 (DIR), U6.20 (VCC); also elsewhere on the board
+5V: C27.1, J9.1, J9.2, J9.3, J9.4, U7.3 (VIN), U7.5 (EN); also elsewhere on the board
/vga-board/BLUE: J10.3; also elsewhere on the board
/vga-board/GREEN: J10.4; also elsewhere on the board
/vga-board/HSYNC: J10.2, R18.2
/vga-board/RED: J10.5; also elsewhere on the board
/vga-board/VGA_BLUE0: J9.29; also elsewhere on the board
/vga-board/VGA_BLUE1: J9.28; also elsewhere on the board
/vga-board/VGA_BLUE2: J9.27; also elsewhere on the board
/vga-board/VGA_BLUE3: J9.26; also elsewhere on the board
/vga-board/VGA_BLUE4: J9.25; also elsewhere on the board
/vga-board/VGA_BLUE5: J9.24; also elsewhere on the board
/vga-board/VGA_BLUE6: J9.23; also elsewhere on the board
/vga-board/VGA_BLUE7: J9.22; also elsewhere on the board
/vga-board/VGA_GREEN0: J9.21; also elsewhere on the board
/vga-board/VGA_GREEN1: J9.20; also elsewhere on the board
/vga-board/VGA_GREEN2: J9.19; also elsewhere on the board
/vga-board/VGA_GREEN3: J9.18; also elsewhere on the board
/vga-board/VGA_GREEN4: J9.17; also elsewhere on the board
/vga-board/VGA_GREEN5: J9.16; also elsewhere on the board
/vga-board/VGA_GREEN6: J9.15; also elsewhere on the board
/vga-board/VGA_GREEN7: J9.14; also elsewhere on the board
/vga-board/VGA_HSYNC: J9.32, U6.3 (A1)
/vga-board/VGA_RED0: J9.13; also elsewhere on the board
/vga-board/VGA_RED1: J9.12; also elsewhere on the board
/vga-board/VGA_RED2: J9.11; also elsewhere on the board
/vga-board/VGA_RED3: J9.10; also elsewhere on the board
/vga-board/VGA_RED4: J9.9; also elsewhere on the board
/vga-board/VGA_RED5: J9.8; also elsewhere on the board
/vga-board/VGA_RED6: J9.7; also elsewhere on the board
/vga-board/VGA_RED7: J9.6; also elsewhere on the board
/vga-board/VGA_VSYNC: J9.30, U6.2 (A0)
/vga-board/VSYNC: J10.1, R17.2
GND: C25.2, C26.2, C27.2, C28.2, D2.1 (K), J9.5, J9.34, J10.6, R21.1, U6.10 (GND), U6.19 (OE), U7.2 (GND); also elsewhere on the board
unnamed: D2.2 (A), R19.2
unnamed: R17.1, U6.18 (B0)
unnamed: R18.1, U6.17 (B1)
unnamed: R20.1, R21.2, U7.1 (FB)
unnamed: L2.1, U7.4 (SW)

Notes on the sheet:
R2R DAC
LED
3V3 BUCK
RGB FPC
SYNC DRIVER
VGA CONN

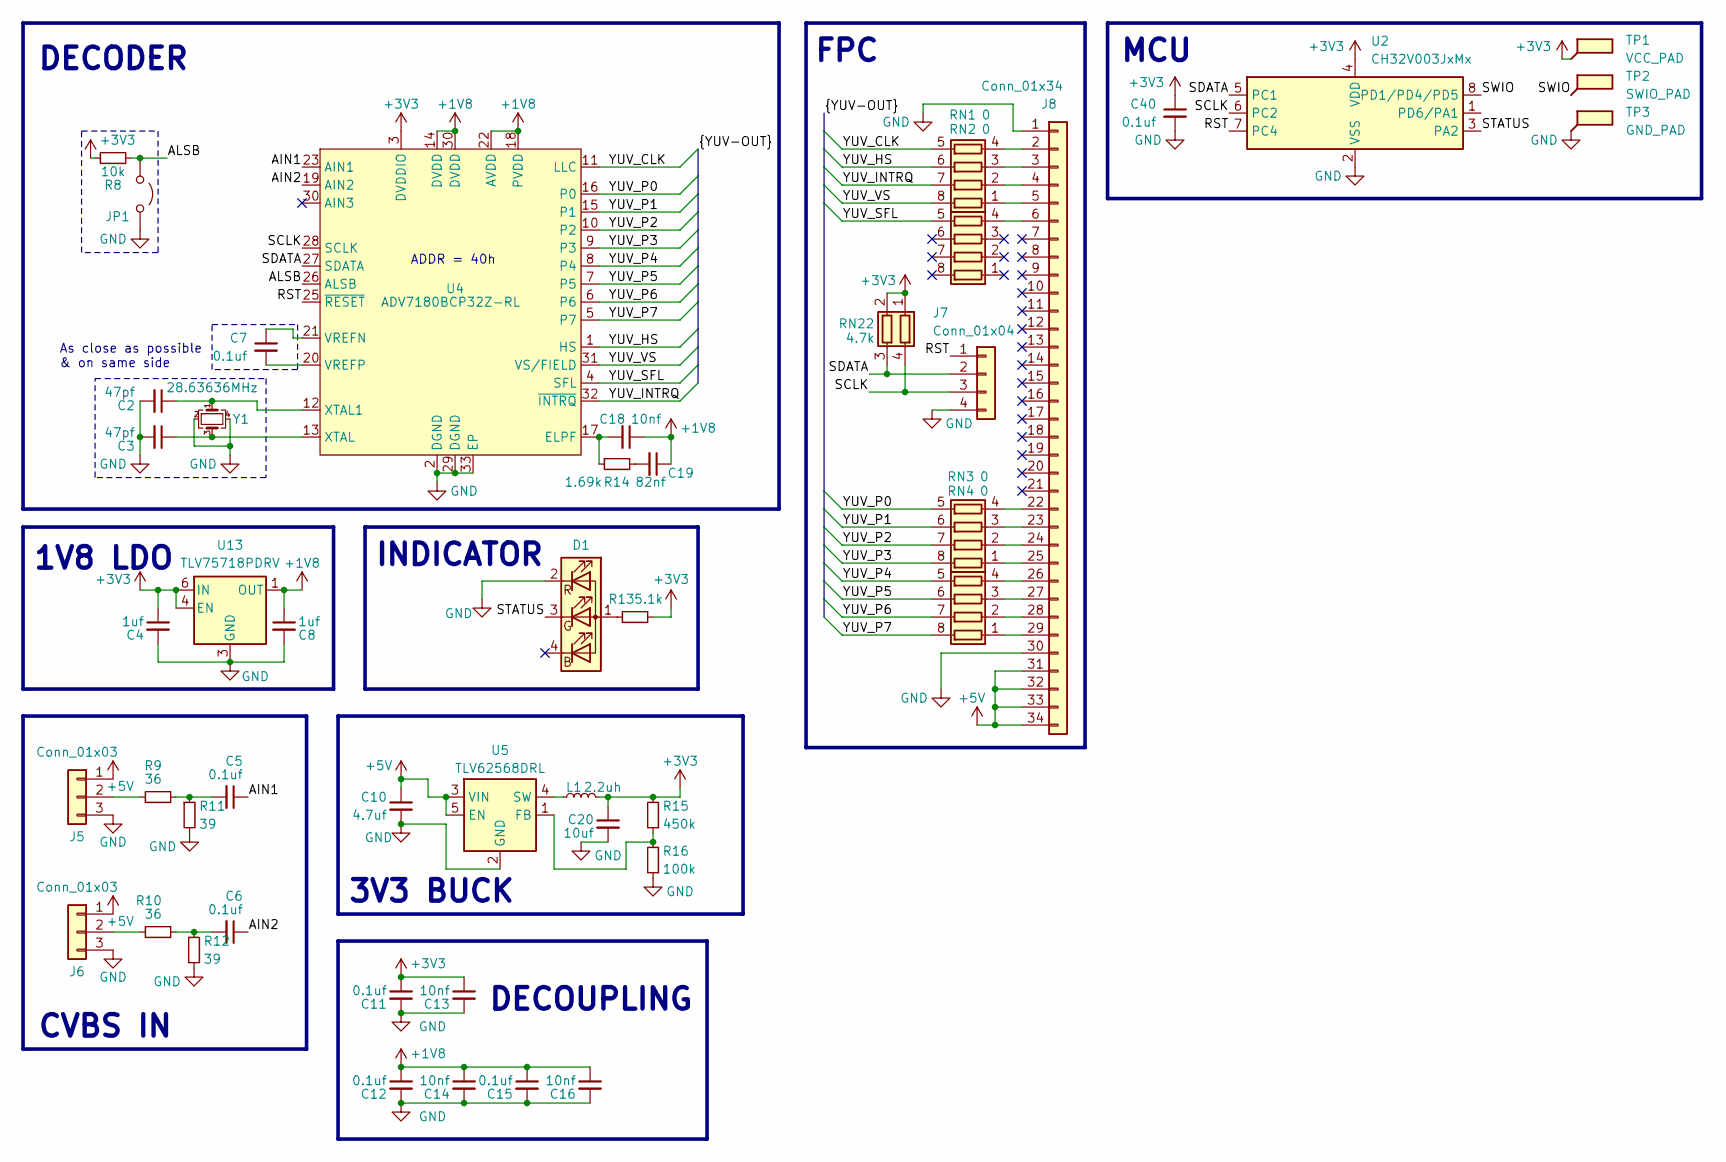
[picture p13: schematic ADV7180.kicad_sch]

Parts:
C2, C3: 47pf; C_0603_1608Metric
C4, C8: 1uf; C_0603_1608Metric
C5, C6, C7, C11, C12, C15, C40: 0.1uf; C_0603_1608Metric
C10: 4.7uf; C_0603_1608Metric
C13, C14, C16, C18: 10nf; C_0603_1608Metric
C19: 82nf; C_0603_1608Metric
C20: 10uf; C_0603_1608Metric
D1: LED-SMD_4P-L1.6-W1.5-BR_TZ-P4-1615
J5, J6: Conn_01x03; PinHeader_1x03_P2.54mm_Vertical
J7: Conn_01x04; PinHeader_1x04_P2.54mm_Vertical
J8: Conn_01x34; FPC-SMD_KH-FG0.5-H2.0-34PIN
JP1: SolderJumper-2_P1.3mm_Open_RoundedPad1.0x1.5mm
L1: 2.2uh; L_0603_1608Metric
R8: 10k; R_0603_1608Metric
R9, R10: 36; R_0603_1608Metric
R11, R12: 39; R_0603_1608Metric
R13: 5.1k; R_0603_1608Metric
R14: 1.69k; R_0603_1608Metric
R15: 450k; R_0603_1608Metric
R16: 100k; R_0603_1608Metric
RN1, RN2, RN3, RN4: 0; R_Array_Convex_4x0603
RN22: 4.7k; R_Array_Convex_2x0603
TP1: VCC_PAD; TestPoint_Pad_D1.5mm
TP2: SWIO_PAD; TestPoint_Pad_D1.5mm
TP3: GND_PAD; TestPoint_Pad_D1.5mm
U2: CH32V003JxMx; SOP-8_3.9x4.9mm_P1.27mm
U4: ADV7180BCP32Z-RL; LFCSP-32-1EP_5x5mm_P0.5mm_EP3.6x3.6mm; LCSC Part C459884
U5: TLV62568DRL; SOT-563
U13: TLV75718PDRV; WSON-6-1EP_2x2mm_P0.65mm_EP1x1.6mm
Y1: 28.63636MHz; Crystal_SMD_Abracon_ABM8AIG-4Pin_3.2x2.5mm

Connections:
+1V8: C8.1, C12.1, C14.1, C15.1, C16.1, C18.1, C19.1, U4.14 (DVDD), U4.18 (PVDD), U4.22 (AVDD), U4.30 (DVDD), U13.1 (OUT)
+3V3: C4.1, C11.1, C13.1, C20.1, C40.1, L1.2, R8.2, R13.2, R15.2, RN22.1 (R1.1), RN22.2 (R2.1), TP1.1, U2.4 (VDD), U4.3 (DVDDIO), U13.4 (EN), U13.6 (IN); also elsewhere on the board
+5V: C10.1, J5.1, J6.1, J8.31, J8.32, J8.33, J8.34, U5.3 (VIN), U5.5 (EN); also elsewhere on the board
/ADV7180-board/AIN1: C5.1, U4.23 (AIN1)
/ADV7180-board/AIN2: C6.1, U4.19 (AIN2)
/ADV7180-board/ALSB: JP1.2 (B), R8.1, U4.26 (ALSB)
/ADV7180-board/RST: J7.1, U2.7 (PC4), U4.25 (~RESET)
/ADV7180-board/SCLK: J7.3, RN22.4 (R1.2), U2.6 (PC2), U4.28 (SCLK)
/ADV7180-board/SDATA: J7.2, RN22.3 (R2.2), U2.5 (PC1), U4.27 (SDATA)
/ADV7180-board/STATUS: D1.3 (GK), U2.3 (PA2)
/ADV7180-board/SWIO: TP2.1, U2.8 (PD1/PD4/PD5)
/ADV7180-board/YUV_CLK: RN1.5 (R4.2), U4.11 (LLC)
/ADV7180-board/YUV_HS: RN1.6 (R3.2), U4.1 (HS)
/ADV7180-board/YUV_INTRQ: RN1.7 (R2.2), U4.32 (~INTRQ)
/ADV7180-board/YUV_P0: RN3.5 (R4.2), U4.16 (P0)
/ADV7180-board/YUV_P1: RN3.6 (R3.2), U4.15 (P1)
/ADV7180-board/YUV_P2: RN3.7 (R2.2), U4.10 (P2)
/ADV7180-board/YUV_P3: RN3.8 (R1.2), U4.9 (P3)
/ADV7180-board/YUV_P4: RN4.5 (R4.2), U4.8 (P4)
/ADV7180-board/YUV_P5: RN4.6 (R3.2), U4.7 (P5)
/ADV7180-board/YUV_P6: RN4.7 (R2.2), U4.6
/ADV7180-board/YUV_P7: RN4.8 (R1.2), U4.5 (P7)
/ADV7180-board/YUV_SFL: RN2.5 (R4.2), U4.4 (SFL)
/ADV7180-board/YUV_VS: RN1.8 (R1.2), U4.31 (VS/FIELD)
GND: C2.2, C3.2, C4.2, C8.2, C10.2, C11.2, C12.2, C13.2, C14.2, C15.2, C16.2, C20.2, C40.2, D1.2 (RK), J5.3, J6.3, J7.4, J8.1, J8.30, JP1.1 (A), R11.2, R12.2, R16.1, TP3.1, U2.2 (VSS), U4.2 (DGND), U4.29 (DGND), U4.33 (EP), U5.2 (GND), U13.3 (GND), U13.7 (GND), Y1.2, Y1.4; also elsewhere on the board
unnamed: C5.2, R9.2, R11.1
unnamed: C6.2, R10.2, R12.1
unnamed: C19.2, R14.2
unnamed: D1.1 (A), R13.1
unnamed: J5.2, R9.1
unnamed: J6.2, R10.1
unnamed: J8.2, RN1.4 (R4.1)
unnamed: J8.3, RN1.3 (R3.1)
unnamed: J8.4, RN1.2 (R2.1)
unnamed: J8.5, RN1.1 (R1.1)
unnamed: J8.6, RN2.4 (R4.1)
unnamed: J8.22, RN3.4 (R4.1)
unnamed: J8.23, RN3.3 (R3.1)
unnamed: J8.24, RN3.2 (R2.1)
unnamed: J8.25, RN3.1 (R1.1)
unnamed: J8.26, RN4.4 (R4.1)
unnamed: J8.27, RN4.3 (R3.1)
unnamed: J8.28, RN4.2 (R2.1)
unnamed: J8.29, RN4.1 (R1.1)
unnamed: C18.2, R14.1, U4.17 (ELPF)
unnamed: C7.1, U4.21 (VREFN)
unnamed: C7.2, U4.20 (VREFP)
unnamed: C2.1, U4.12 (XTAL1), Y1.1
unnamed: C3.1, U4.13 (XTAL), Y1.3
unnamed: R15.1, R16.2, U5.1 (FB)
unnamed: L1.1, U5.4 (SW)

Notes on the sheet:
3V3 BUCK
As close as possible & on same side
1V8 LDO
FPC
MCU
ADDR = 40h
DECOUPLING
INDICATOR
DECODER
CVBS IN

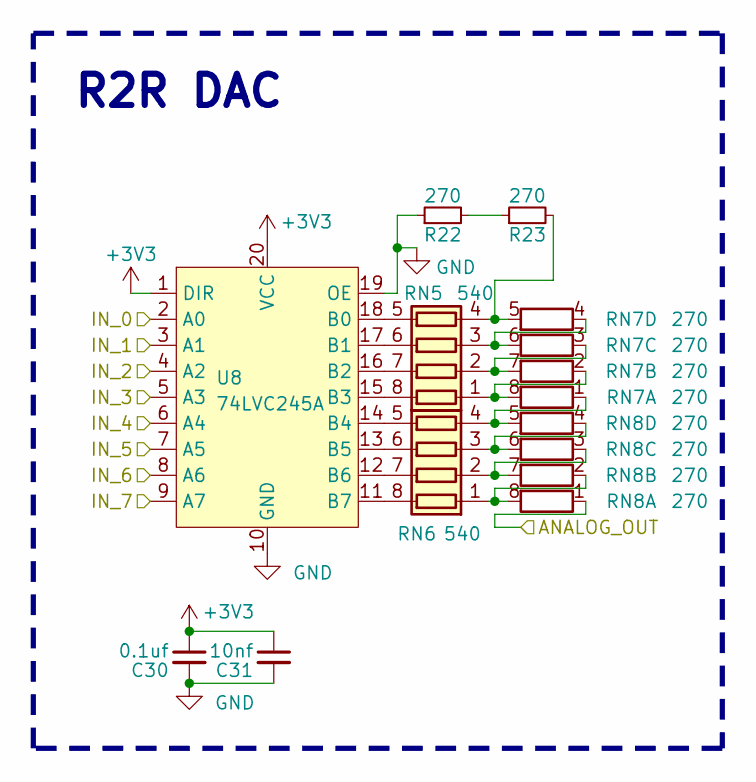
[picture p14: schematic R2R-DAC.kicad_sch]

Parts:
C30: 0.1uf; C_0603_1608Metric
C31: 10nf; C_0603_1608Metric
R22, R23: 270; R_0603_1608Metric
RN5, RN6: 540; R_Array_Convex_4x0603
RN7, RN8: 270; R_Array_Convex_4x0603
U8: 74LVC245A; TSSOP-20_4.4x6.5mm_P0.65mm

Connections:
+3V3: C30.1, C31.1, U8.1 (DIR), U8.20 (VCC); also elsewhere on the board
/vga-board/RED: RN8.1 (R1.1); also elsewhere on the board
/vga-board/VGA_RED0: U8.2 (A0); also elsewhere on the board
/vga-board/VGA_RED1: U8.3 (A1); also elsewhere on the board
/vga-board/VGA_RED2: U8.4 (A2); also elsewhere on the board
/vga-board/VGA_RED3: U8.5 (A3); also elsewhere on the board
/vga-board/VGA_RED4: U8.6 (A4); also elsewhere on the board
/vga-board/VGA_RED5: U8.7 (A5); also elsewhere on the board
/vga-board/VGA_RED6: U8.8 (A6); also elsewhere on the board
/vga-board/VGA_RED7: U8.9 (A7); also elsewhere on the board
GND: C30.2, C31.2, R22.1, U8.10 (GND), U8.19 (OE); also elsewhere on the board
unnamed: R22.2, R23.1
unnamed: RN5.1 (R1.1), RN7.2 (R2.1), RN7.8 (R1.2)
unnamed: RN5.8 (R1.2), U8.15 (B3)
unnamed: RN5.2 (R2.1), RN7.3 (R3.1), RN7.7 (R2.2)
unnamed: RN5.7 (R2.2), U8.16 (B2)
unnamed: RN5.3 (R3.1), RN7.4 (R4.1), RN7.6 (R3.2)
unnamed: RN5.6 (R3.2), U8.17 (B1)
unnamed: R23.2, RN5.4 (R4.1), RN7.5 (R4.2)
unnamed: RN5.5 (R4.2), U8.18 (B0)
unnamed: RN6.1 (R1.1), RN8.2 (R2.1), RN8.8 (R1.2)
unnamed: RN6.8 (R1.2), U8.11 (B7)
unnamed: RN6.2 (R2.1), RN8.3 (R3.1), RN8.7 (R2.2)
unnamed: RN6.7 (R2.2), U8.12 (B6)
unnamed: RN6.3 (R3.1), RN8.4 (R4.1), RN8.6 (R3.2)
unnamed: RN6.6 (R3.2), U8.13 (B5)
unnamed: RN6.4 (R4.1), RN7.1 (R1.1), RN8.5 (R4.2)
unnamed: RN6.5 (R4.2), U8.14 (B4)

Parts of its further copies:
C32, C34: 0.1uf; C_0603_1608Metric
C33, C35: 10nf; C_0603_1608Metric
R24, R25, R26, R27: 270; R_0603_1608Metric
RN9, RN10, RN13, RN14: 540; R_Array_Convex_4x0603
RN11, RN12, RN15, RN16: 270; R_Array_Convex_4x0603
U9, U10: 74LVC245A; TSSOP-20_4.4x6.5mm_P0.65mm

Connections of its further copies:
+3V3: C32.1, C33.1, C34.1, C35.1, U9.1 (DIR), U9.20 (VCC), U10.1 (DIR), U10.20 (VCC); also elsewhere on the board
/vga-board/BLUE: RN12.1 (R1.1); also elsewhere on the board
/vga-board/GREEN: RN16.1 (R1.1); also elsewhere on the board
/vga-board/VGA_BLUE0: U9.2 (A0); also elsewhere on the board
/vga-board/VGA_BLUE1: U9.3 (A1); also elsewhere on the board
/vga-board/VGA_BLUE2: U9.4 (A2); also elsewhere on the board
/vga-board/VGA_BLUE3: U9.5 (A3); also elsewhere on the board
/vga-board/VGA_BLUE4: U9.6 (A4); also elsewhere on the board
/vga-board/VGA_BLUE5: U9.7 (A5); also elsewhere on the board
/vga-board/VGA_BLUE6: U9.8 (A6); also elsewhere on the board
/vga-board/VGA_BLUE7: U9.9 (A7); also elsewhere on the board
/vga-board/VGA_GREEN0: U10.2 (A0); also elsewhere on the board
/vga-board/VGA_GREEN1: U10.3 (A1); also elsewhere on the board
/vga-board/VGA_GREEN2: U10.4 (A2); also elsewhere on the board
/vga-board/VGA_GREEN3: U10.5 (A3); also elsewhere on the board
/vga-board/VGA_GREEN4: U10.6 (A4); also elsewhere on the board
/vga-board/VGA_GREEN5: U10.7 (A5); also elsewhere on the board
/vga-board/VGA_GREEN6: U10.8 (A6); also elsewhere on the board
/vga-board/VGA_GREEN7: U10.9 (A7); also elsewhere on the board
GND: C32.2, C33.2, C34.2, C35.2, R24.1, R26.1, U9.10 (GND), U9.19 (OE), U10.10 (GND), U10.19 (OE); also elsewhere on the board
unnamed: R24.2, R25.1
unnamed: R26.2, R27.1
unnamed: RN9.8 (R1.2), U9.15 (B3)
unnamed: RN9.7 (R2.2), U9.16 (B2)
unnamed: RN9.6 (R3.2), U9.17 (B1)
unnamed: RN9.5 (R4.2), U9.18 (B0)
unnamed: RN10.1 (R1.1), RN12.2 (R2.1), RN12.8 (R1.2)
unnamed: RN10.8 (R1.2), U9.11 (B7)
unnamed: RN10.2 (R2.1), RN12.3 (R3.1), RN12.7 (R2.2)
unnamed: RN10.7 (R2.2), U9.12 (B6)
unnamed: RN10.3 (R3.1), RN12.4 (R4.1), RN12.6 (R3.2)
unnamed: RN10.6 (R3.2), U9.13 (B5)
unnamed: RN10.4 (R4.1), RN11.1 (R1.1), RN12.5 (R4.2)
unnamed: RN10.5 (R4.2), U9.14 (B4)
unnamed: RN9.1 (R1.1), RN11.2 (R2.1), RN11.8 (R1.2)
unnamed: RN9.2 (R2.1), RN11.3 (R3.1), RN11.7 (R2.2)
unnamed: RN9.3 (R3.1), RN11.4 (R4.1), RN11.6 (R3.2)
unnamed: R25.2, RN9.4 (R4.1), RN11.5 (R4.2)
unnamed: RN13.1 (R1.1), RN15.2 (R2.1), RN15.8 (R1.2)
unnamed: RN13.8 (R1.2), U10.15 (B3)
unnamed: RN13.2 (R2.1), RN15.3 (R3.1), RN15.7 (R2.2)
unnamed: RN13.7 (R2.2), U10.16 (B2)
unnamed: RN13.3 (R3.1), RN15.4 (R4.1), RN15.6 (R3.2)
unnamed: RN13.6 (R3.2), U10.17 (B1)
unnamed: R27.2, RN13.4 (R4.1), RN15.5 (R4.2)
unnamed: RN13.5 (R4.2), U10.18 (B0)
unnamed: RN14.1 (R1.1), RN16.2 (R2.1), RN16.8 (R1.2)
unnamed: RN14.8 (R1.2), U10.11 (B7)
unnamed: RN14.2 (R2.1), RN16.3 (R3.1), RN16.7 (R2.2)
unnamed: RN14.7 (R2.2), U10.12 (B6)
unnamed: RN14.3 (R3.1), RN16.4 (R4.1), RN16.6 (R3.2)
unnamed: RN14.6 (R3.2), U10.13 (B5)
unnamed: RN14.4 (R4.1), RN15.1 (R1.1), RN16.5 (R4.2)
unnamed: RN14.5 (R4.2), U10.14 (B4)

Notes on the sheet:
R2R DAC

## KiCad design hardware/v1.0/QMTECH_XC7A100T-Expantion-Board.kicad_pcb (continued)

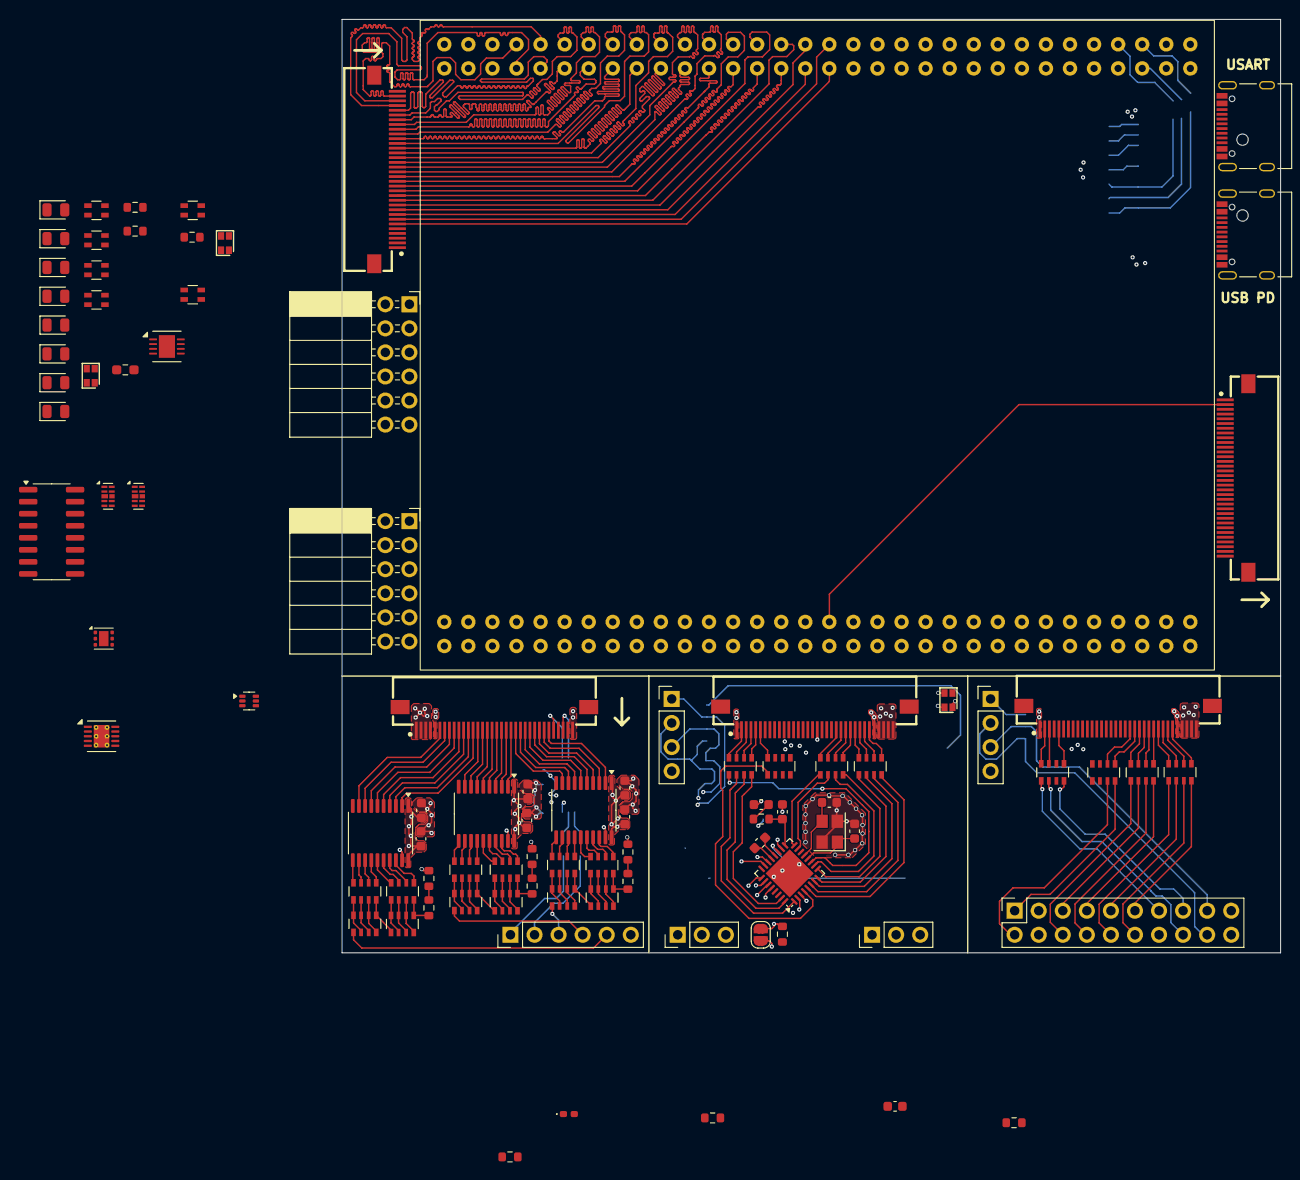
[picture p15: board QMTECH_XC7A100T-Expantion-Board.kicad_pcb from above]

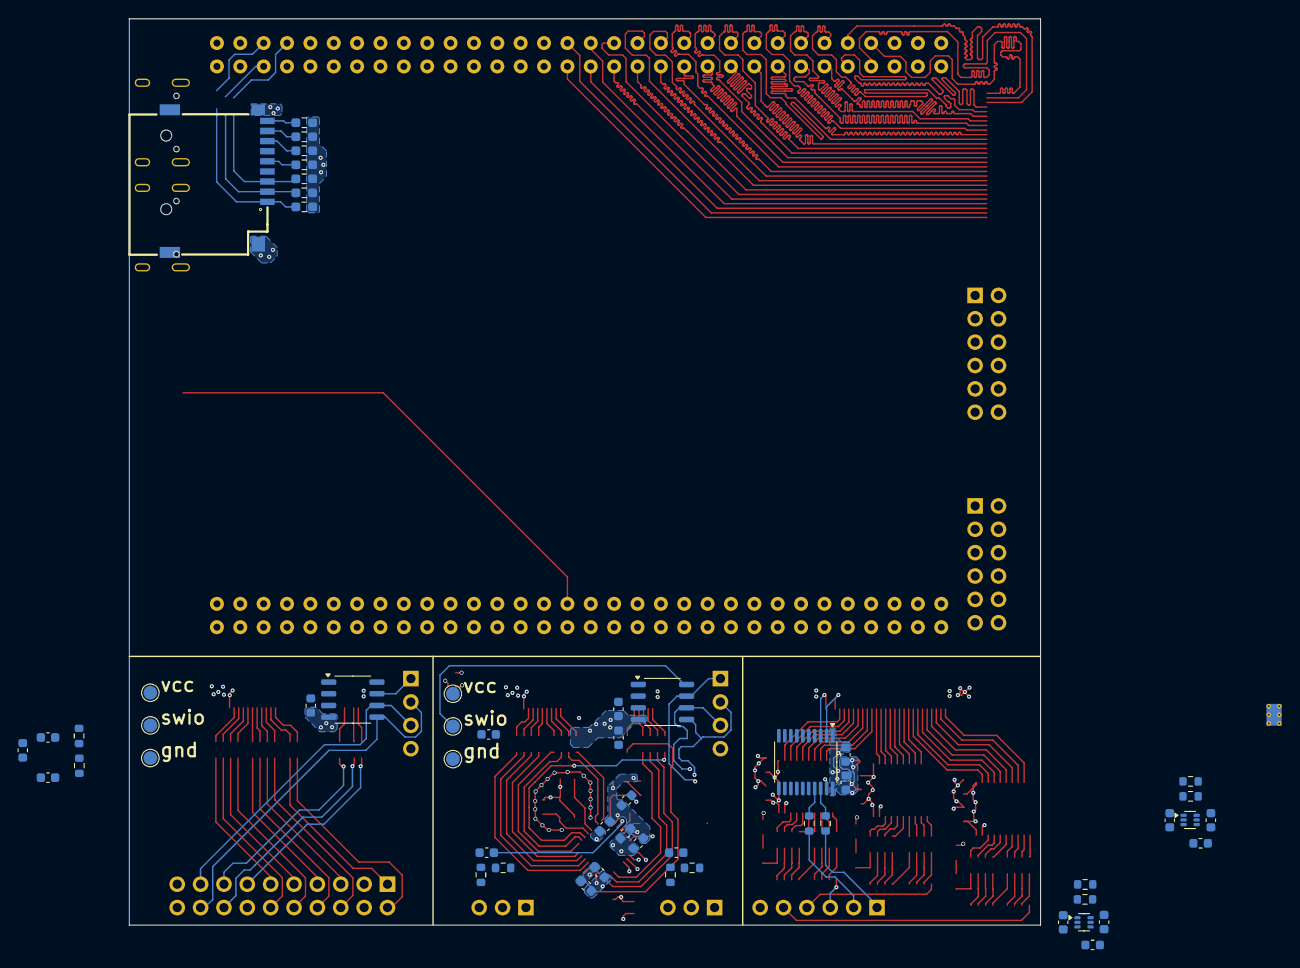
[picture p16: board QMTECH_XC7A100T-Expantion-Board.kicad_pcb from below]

Board: 4 copper layers, 99.1 x 98.5 mm, 148 parts (54 on the bottom side), 274 nets.

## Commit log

2025-04-28 initial push
    [ADV7180.kicad_sch, OV7725-board.kicad_sch, QMTECH_XC7A100T-Expantion-Board.kicad_pcb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]
2025-05-10 updated project to Kicad version 9.0
    [ADV7180.kicad_sch, OV7725-board.kicad_sch, QMTECH_XC7A100T-Expantion-Board.kicad_pcb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]
2025-06-12 added pmod connectors instead of leds
    [ADV7180.kicad_sch, OV7725-board.kicad_sch, QMTECH_XC7A100T-Expantion-Board.kicad_pcb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]
2025-06-13 first schematic iteration done
    [ADV7180.kicad_sch, OV7725-board.kicad_sch, QMTECH_XC7A100T-Expantion-Board.kicad_pcb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]
2025-06-13 did PORT0 routing
    [ADV7180.kicad_sch, OV7725-board.kicad_sch, QMTECH_XC7A100T-Expantion-Board.kicad_pcb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]
2025-06-16 redoing 3v3 regulators
    [ADV7180.kicad_sch, OV7725-board.kicad_sch, QMTECH_XC7A100T-Expantion-Board.kicad_pcb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]
2025-06-19 finished mainboard + progress on peripherals
    [OV7725-board.kicad_sch, QMTECH_XC7A100T-Expantion-Board.kicad_sch]
2025-06-20 finished first draft, still DRC errors
    [ADV7180.kicad_sch, vga-board.kicad_sch]
2025-06-21 progress with drc errors
    [QMTECH_XC7A100T-Expantion-Board.kicad_sch]
2025-06-22 first draft complete
    [QMTECH_XC7A100T-Expantion-Board.kicad_sch]
2025-06-24 upped trace clearances
2025-06-24 changed some net classes colors
    [QMTECH_XC7A100T-Expantion-Board.kicad_sch]
2025-07-05 added version numbers + updated ibom & schematics
2025-07-05 added pin values on silkscreen
2025-07-05 generated first gerbers
    [QMTECH_XC7A100T-Expantion-Board-B_Cu.gbl, QMTECH_XC7A100T-Expantion-Board-B_Mask.gbs, QMTECH_XC7A100T-Expantion-Board-B_Paste.gbp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]
2025-07-07 added tvs diode+changed inductors
    [ADV7180.kicad_sch, OV7725-board.kicad_sch, QMTECH_XC7A100T-Expantion-Board.kicad_sch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]
2025-07-14 generated final gerbers for v1.0
    [QMTECH_XC7A100T-Expantion-Board-B_Cu.gbl, QMTECH_XC7A100T-Expantion-Board-B_Mask.gbs, QMTECH_XC7A100T-Expantion-Board-B_Paste.gbp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]
2025-07-15 updated copper thieving
    [QMTECH_XC7A100T-Expantion-Board-B_Cu.gbl, QMTECH_XC7A100T-Expantion-Board-B_Mask.gbs, QMTECH_XC7A100T-Expantion-Board-B_Paste.gbp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]
